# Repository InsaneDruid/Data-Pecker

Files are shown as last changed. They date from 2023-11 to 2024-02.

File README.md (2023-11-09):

# The Data Pecker - a DB High-Res clone
The Data Pecker is a 100% compatible clone of the DB High-Res graphics board for PET/CBM 8000 series computers from 1982.
It implements all the features, with the option to build a 62256-based RAM-board instead of the original one using eight 6116.
Most of the components are readily available. Chips not available from Mouser or Digikey can still be purchased from a variety of sources in China. 

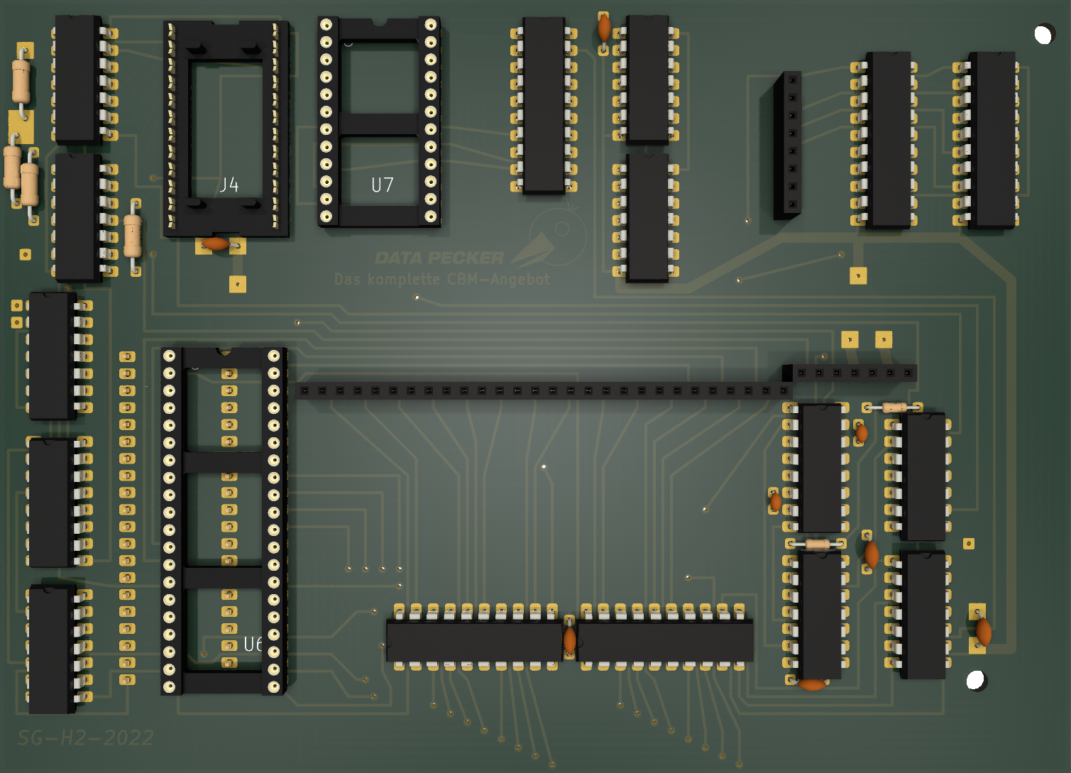
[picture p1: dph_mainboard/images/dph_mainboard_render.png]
Data Pecker render


[Schematic](https://github.com/InsaneDruid/Data-Pecker/blob/main/dph_mainboard/dph_mainboard.pdf "Schematic")  

[Bill of Materials](https://htmlpreview.github.io/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 "Bill of Materials")

[Wire connections](https://github.com/InsaneDruid/Data-Pecker/blob/main/dph_mainboard/dph_mainboard_connections.pdf "Wire connections" )
## The original RAM Board
The is the true-to-the-original version of the RAM board containing eight 6116 SRAM ICs.

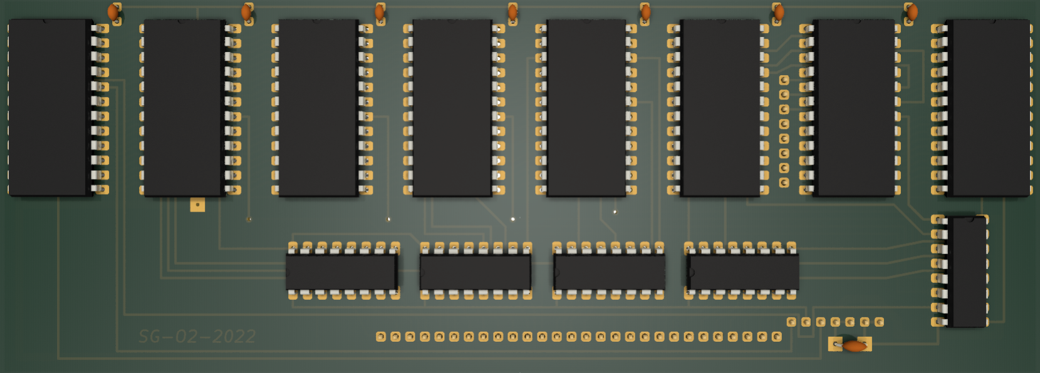
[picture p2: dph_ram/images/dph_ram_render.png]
Original RAM Board render


[Schematic](https://github.com/InsaneDruid/Data-Pecker/blob/main/dph_ram/dph_ram.pdf "Schematic")  

[Bill of Materials](https://htmlpreview.github.io/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 "Bill of Materials")

## The simplified RAM Board
This version replaces the old SRAM chips with a more modern 62256.

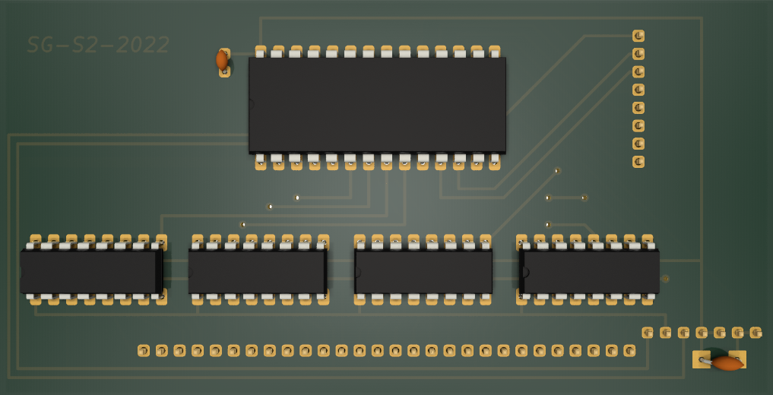
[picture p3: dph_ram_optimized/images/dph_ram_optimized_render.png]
Simplified RAM Board render


[Schematic](https://github.com/InsaneDruid/Data-Pecker/blob/main/dph_ram_optimized/dph_ram_optimized.pdf "Schematic")  

[Bill of Materials](https://htmlpreview.github.io/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 "Bill of Materials")

## The Firmware
There are several ways to get both the programmed 2332A	ROM and TBP18s030 PROM	
chips for the Low Speed Graphik. One is to use U29 and U11 from a original HSG. 
This works well and is especially interesting for those seeking to replace a broken original HSG pcb.

The other possibility is to program a 2532 EPROM replacing U29 and a 18S030 PROM (or compatible, like 82S123, 27S19, 6331, 74S288, 7603a)
replacing U11. The firmware needed for flashing can be found on the web. The 18S030 can also be replaced by a GAL.

## The License
This work is licensed under a Creative Commons Attribution-ShareAlike 4.0 International License.  
See https://creativecommons.org/licenses/by-sa/4.0/.

## The Credits
This work would not have been possible without the help from a bunch of amazing people from [VzEkC e. V. forums](https://forum.classic-computing.de/forum/ "forum.classic-computing.de"). Many thanks go out to:

* *Toast_r* - for providing reference images and ohming out the hidden traces

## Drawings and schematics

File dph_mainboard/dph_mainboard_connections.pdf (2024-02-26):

## IDC PCB connector DIL male, 24-pin, RM 2.54/15.24 ribbon cable

# DATA PECKER wire connections

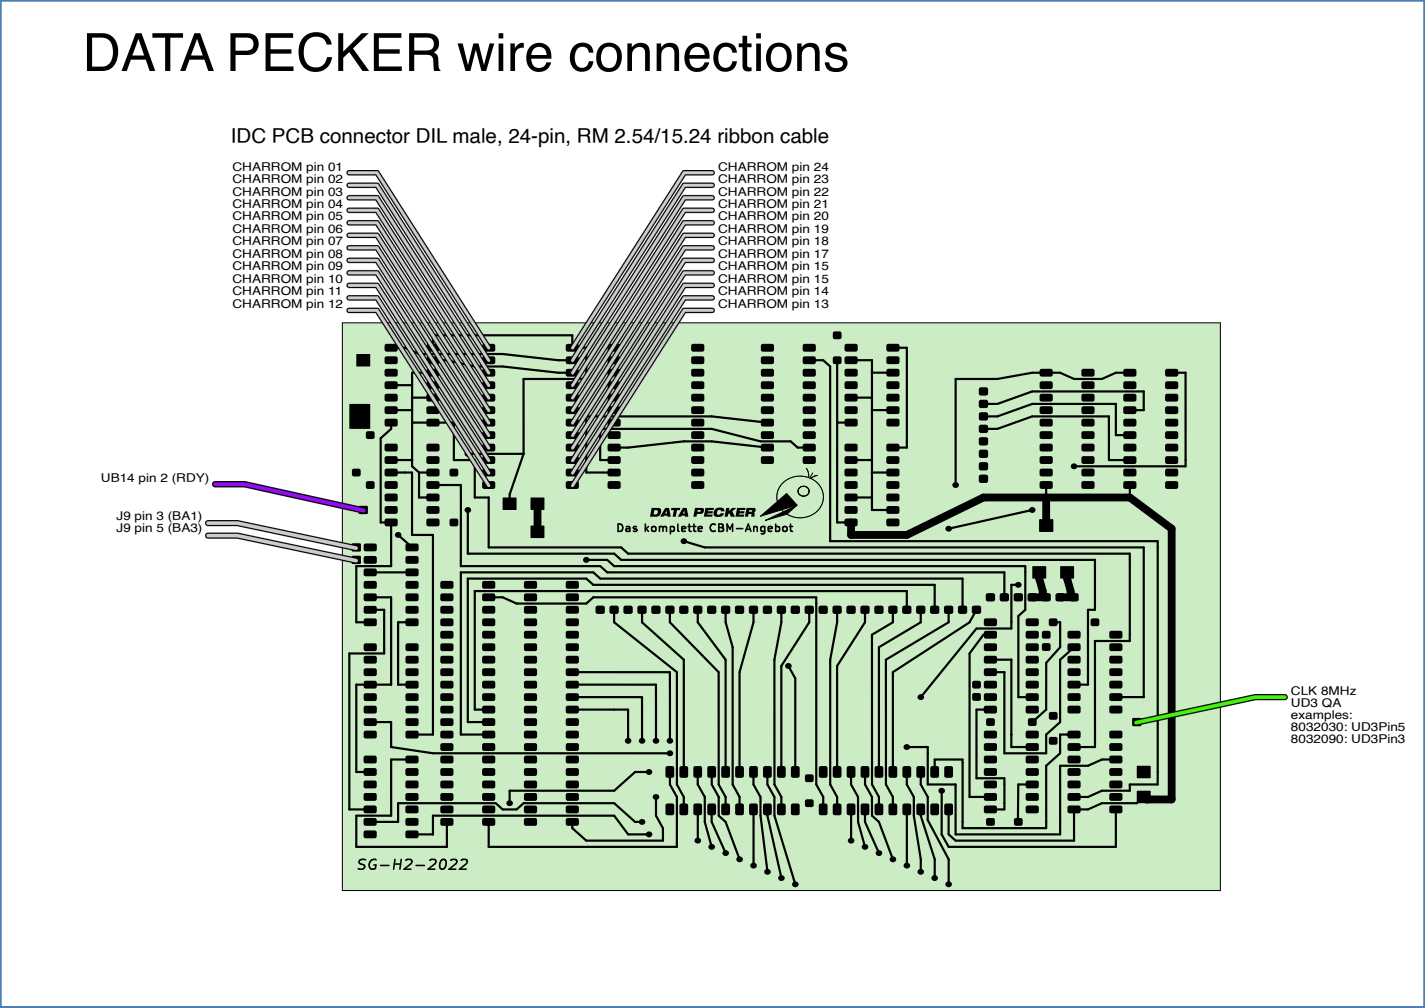
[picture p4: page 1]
CHARROM pin 12; CHARROM pin 24 CHARROM pin 23 CHARROM pin 22 CHARROM pin 21 CHARROM pin 20 CHARROM pin 19 CHARROM pin 18 CHARROM pin 17 CHARROM pin 15 CHARROM pin 15 CHARROM pin 14 CHARROM pin 13; UB14 pin 2 (RDY); J9 pin 3 (BA1); CHARROM pin 01 CHARROM pin 02 CHARROM pin 03 CHARROM pin 04 CHARROM pin 05 CHARROM pin 06 CHARROM pin 07 CHARROM pin 08 CHARROM pin 09 CHARROM pin 10 CHARROM pin 11; J9 pin 5 (BA3); CLK 8MHz UD3 QA examples: 8032030: UD3Pin5 8032090: UD3Pin3

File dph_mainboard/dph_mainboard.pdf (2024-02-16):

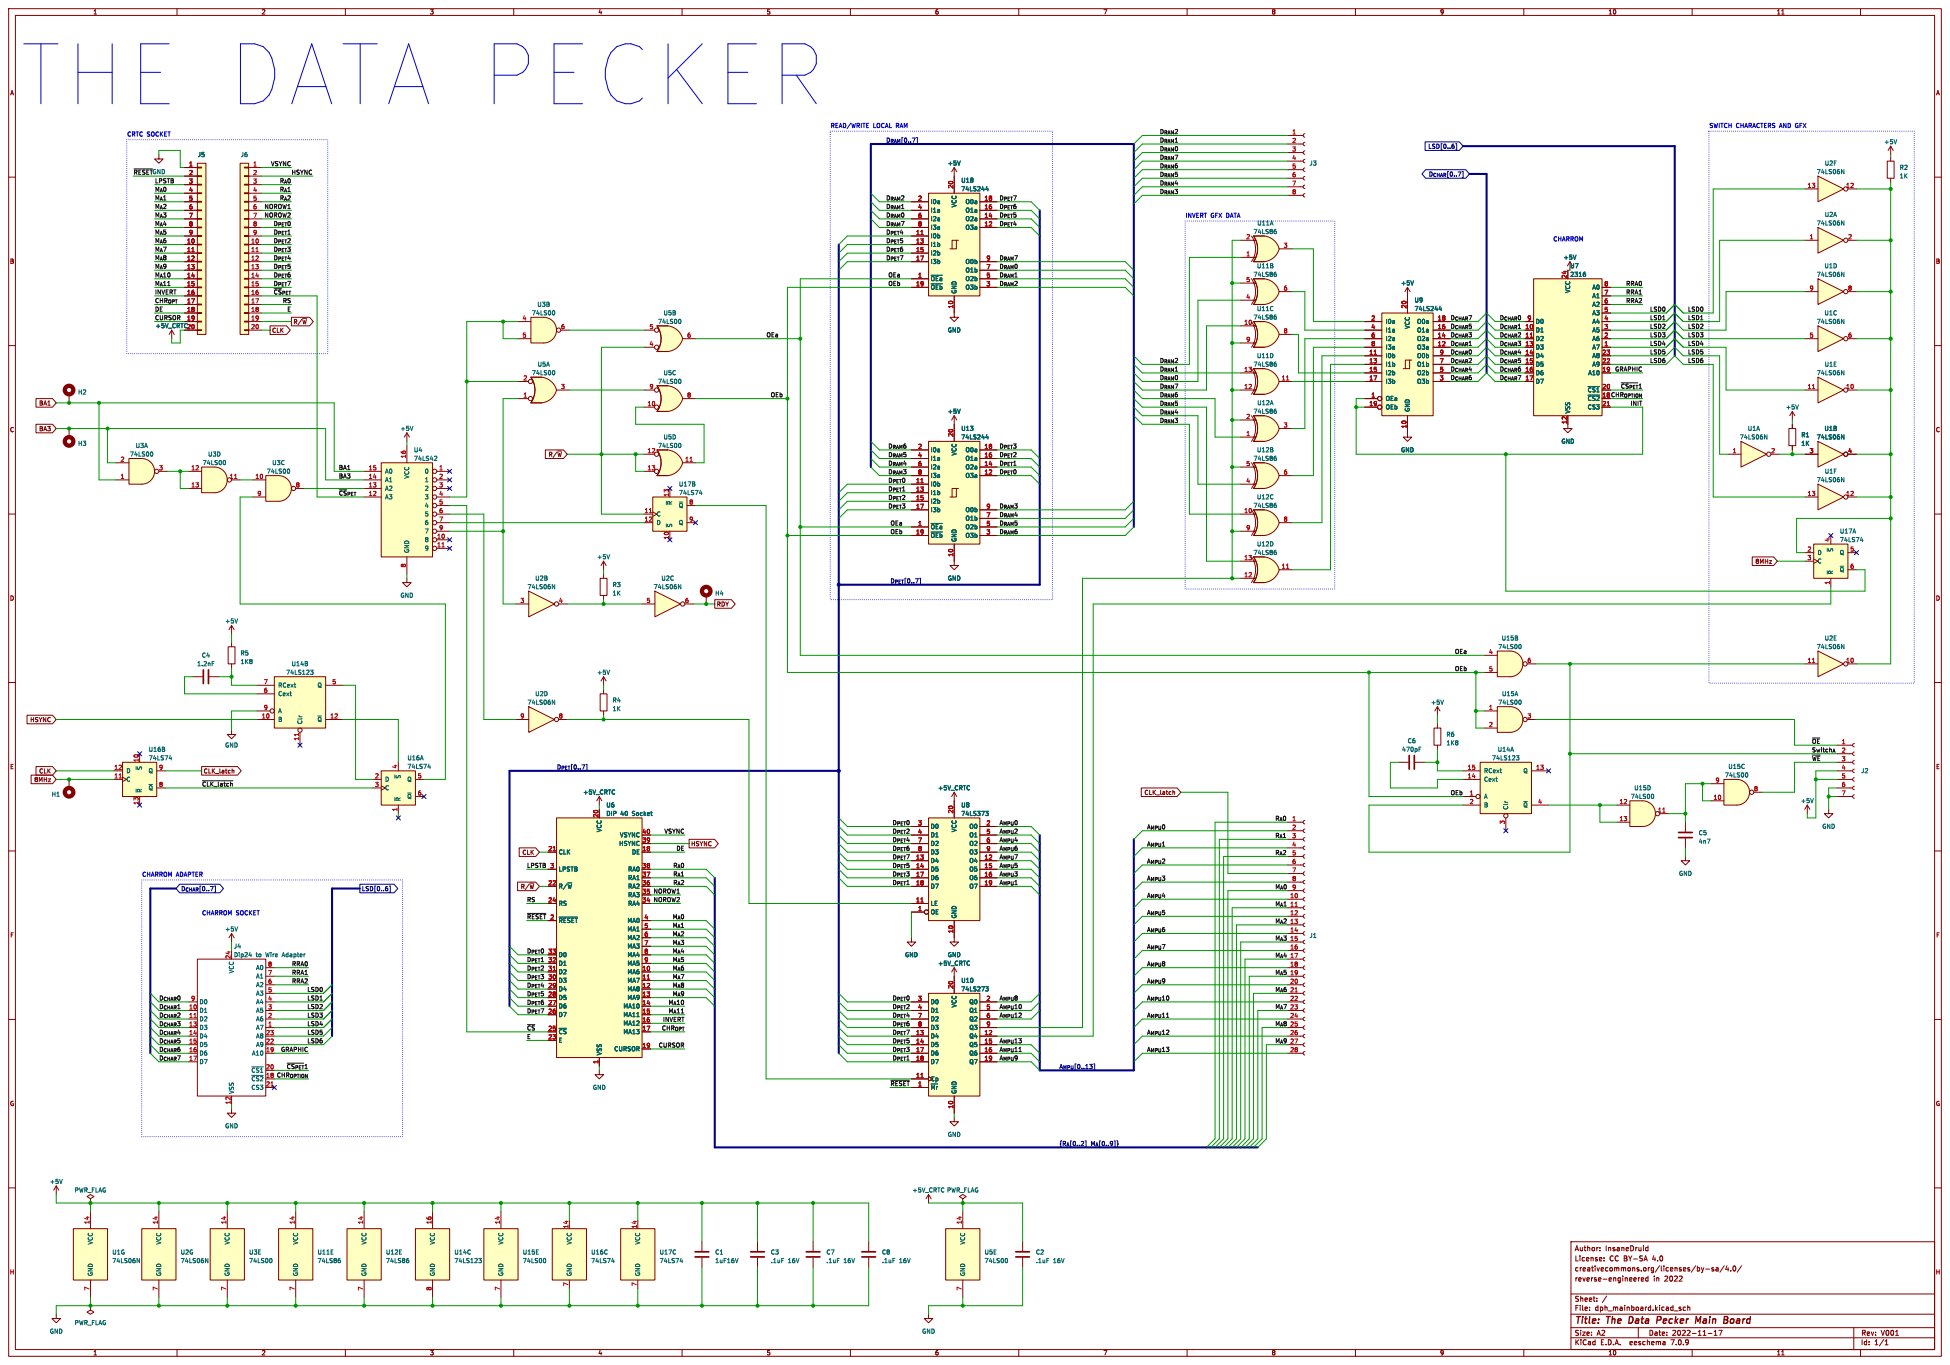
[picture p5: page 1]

SWITCH CHARACTERS AND GFX

1 MA6 10 MA7 11 MA8 12 MA9 13 MA10 14 MA11 15 MA12 16 MA13 17 DE 18 CURSOR 19 ~{RESET} 2 VCC 20 CLK 21 R/~{W} 22 E

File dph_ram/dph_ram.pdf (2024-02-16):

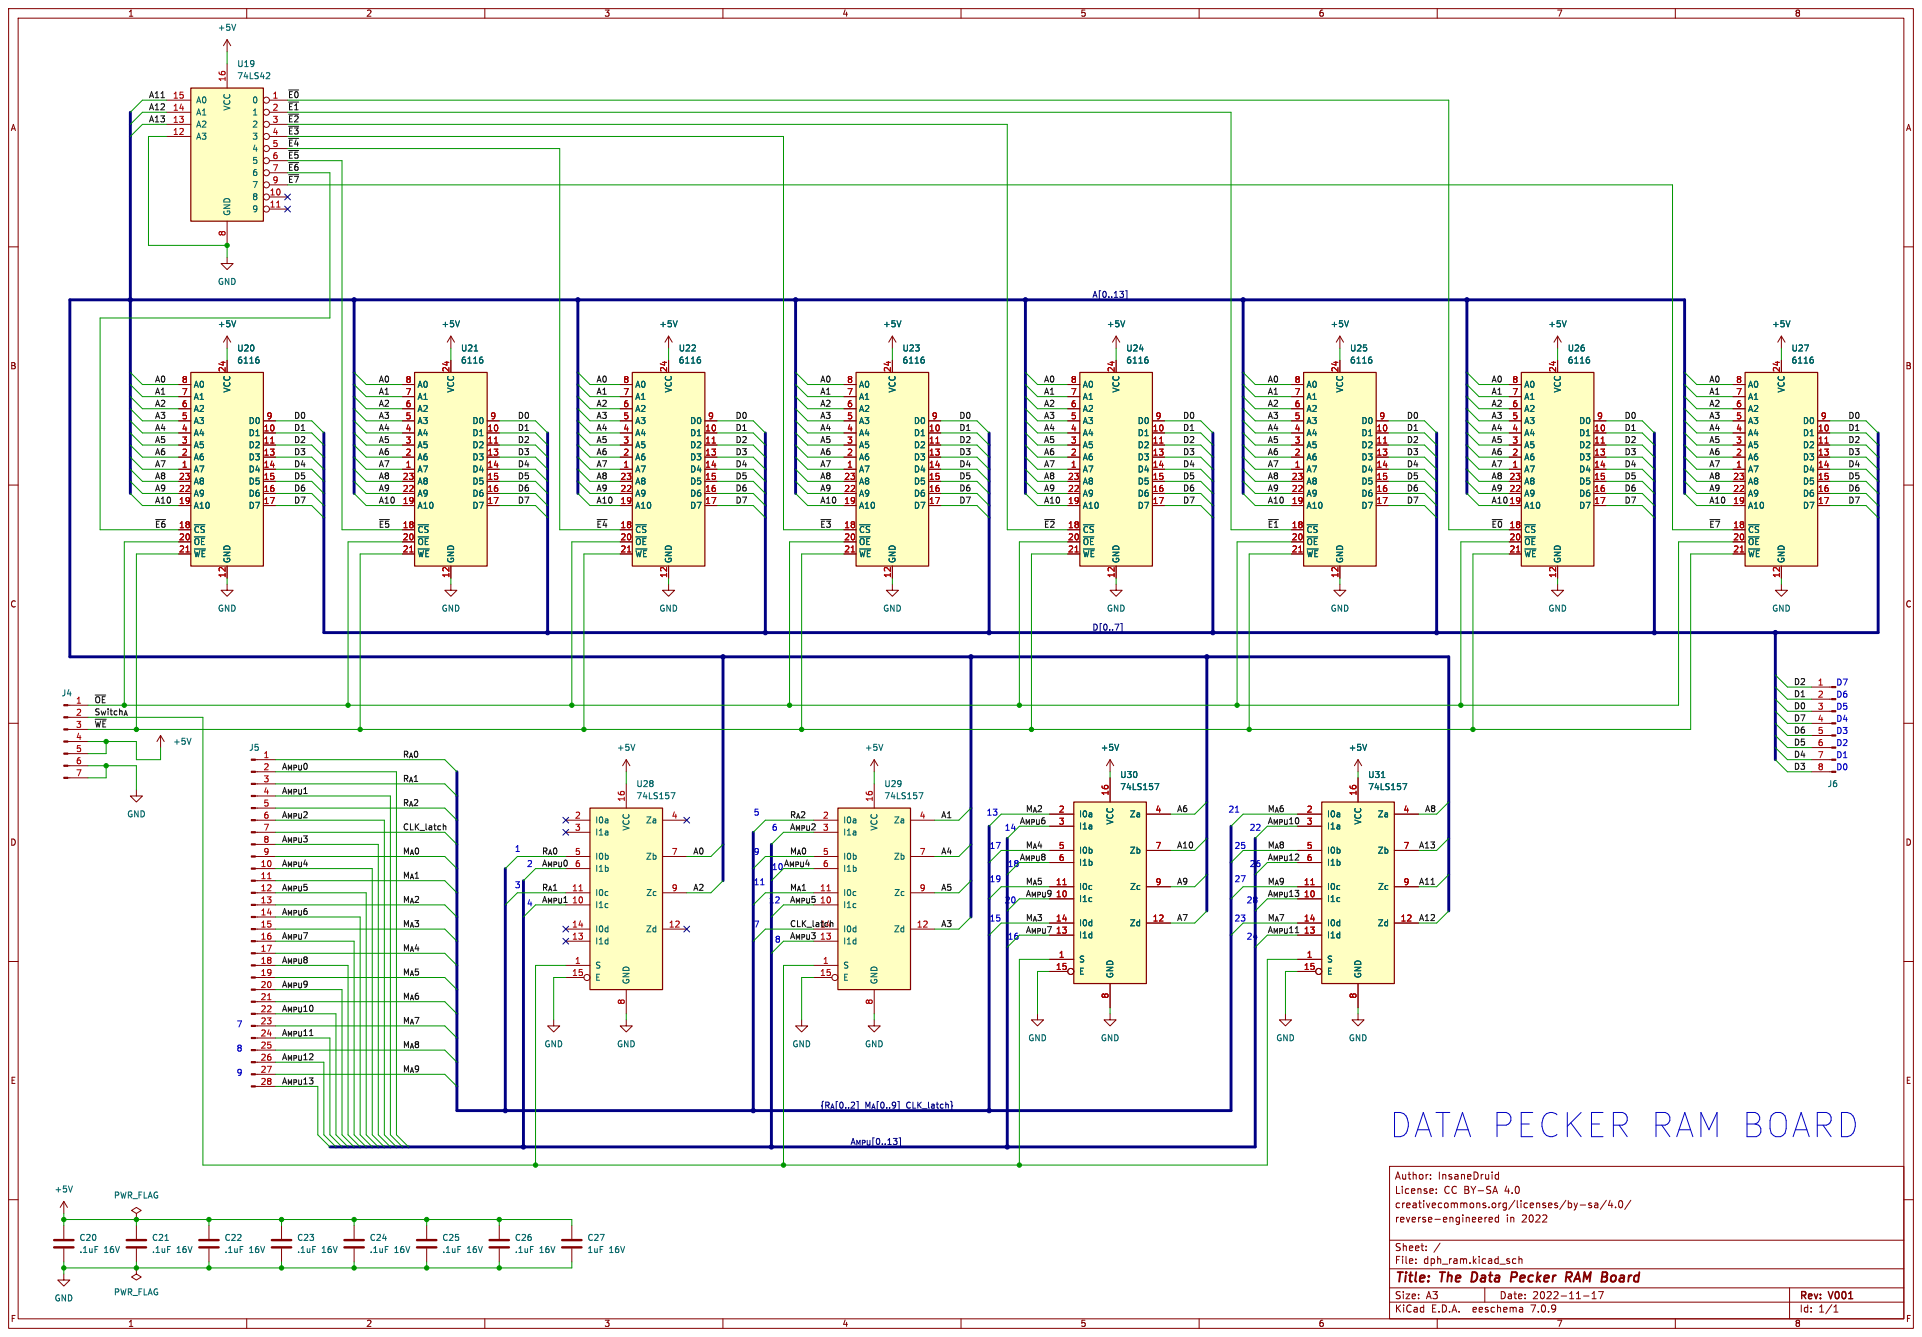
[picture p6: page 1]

Id: 1/1 Title: The Data Pecker RAM Board

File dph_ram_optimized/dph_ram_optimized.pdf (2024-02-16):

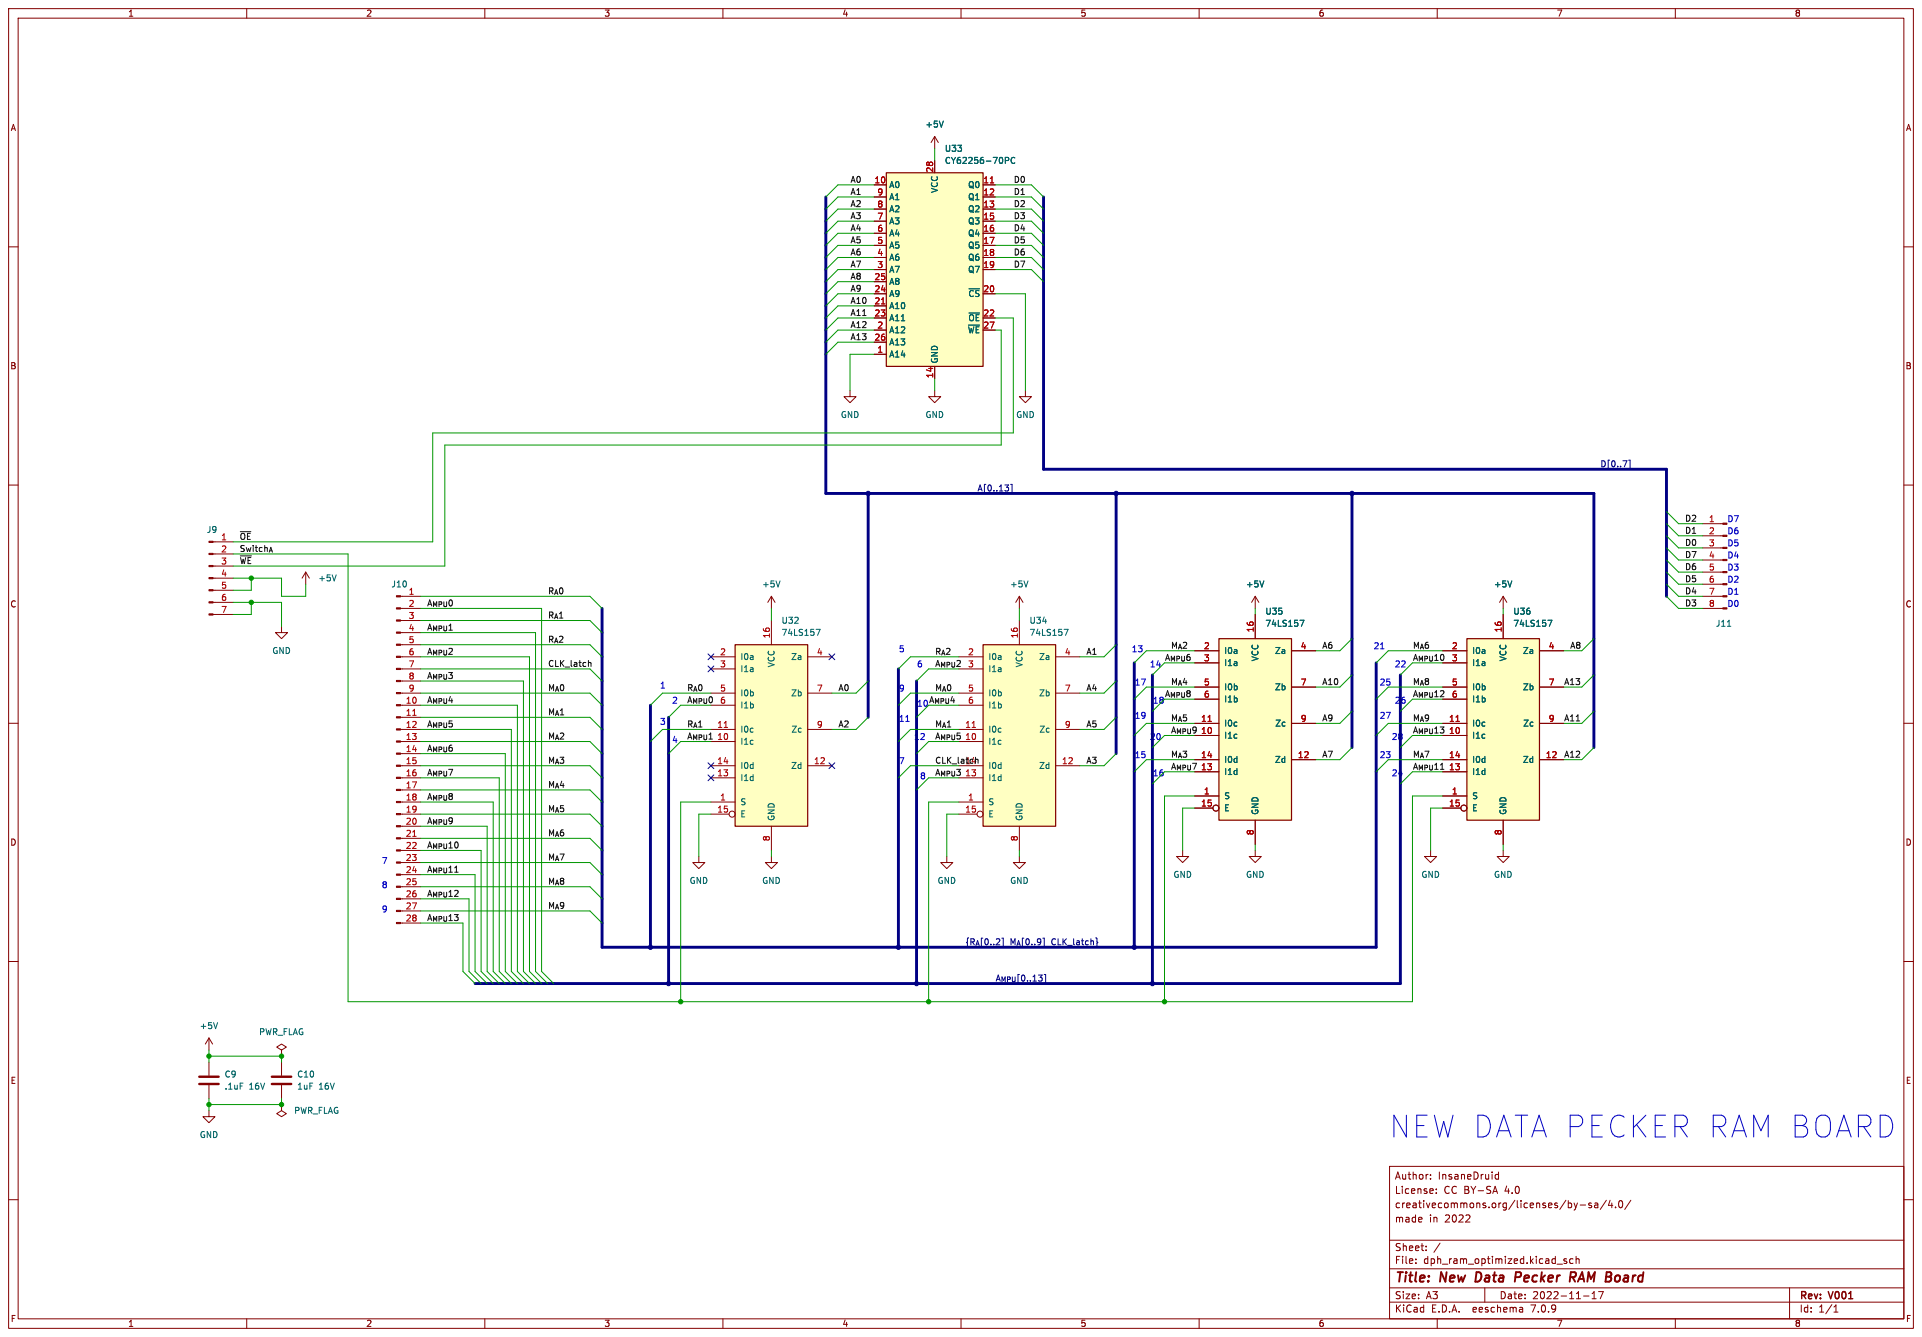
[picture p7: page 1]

File: dph_ram_optimized.kicad_sch Sheet: / made in 2022

Id: 1/1 Title: New Data Pecker RAM Board

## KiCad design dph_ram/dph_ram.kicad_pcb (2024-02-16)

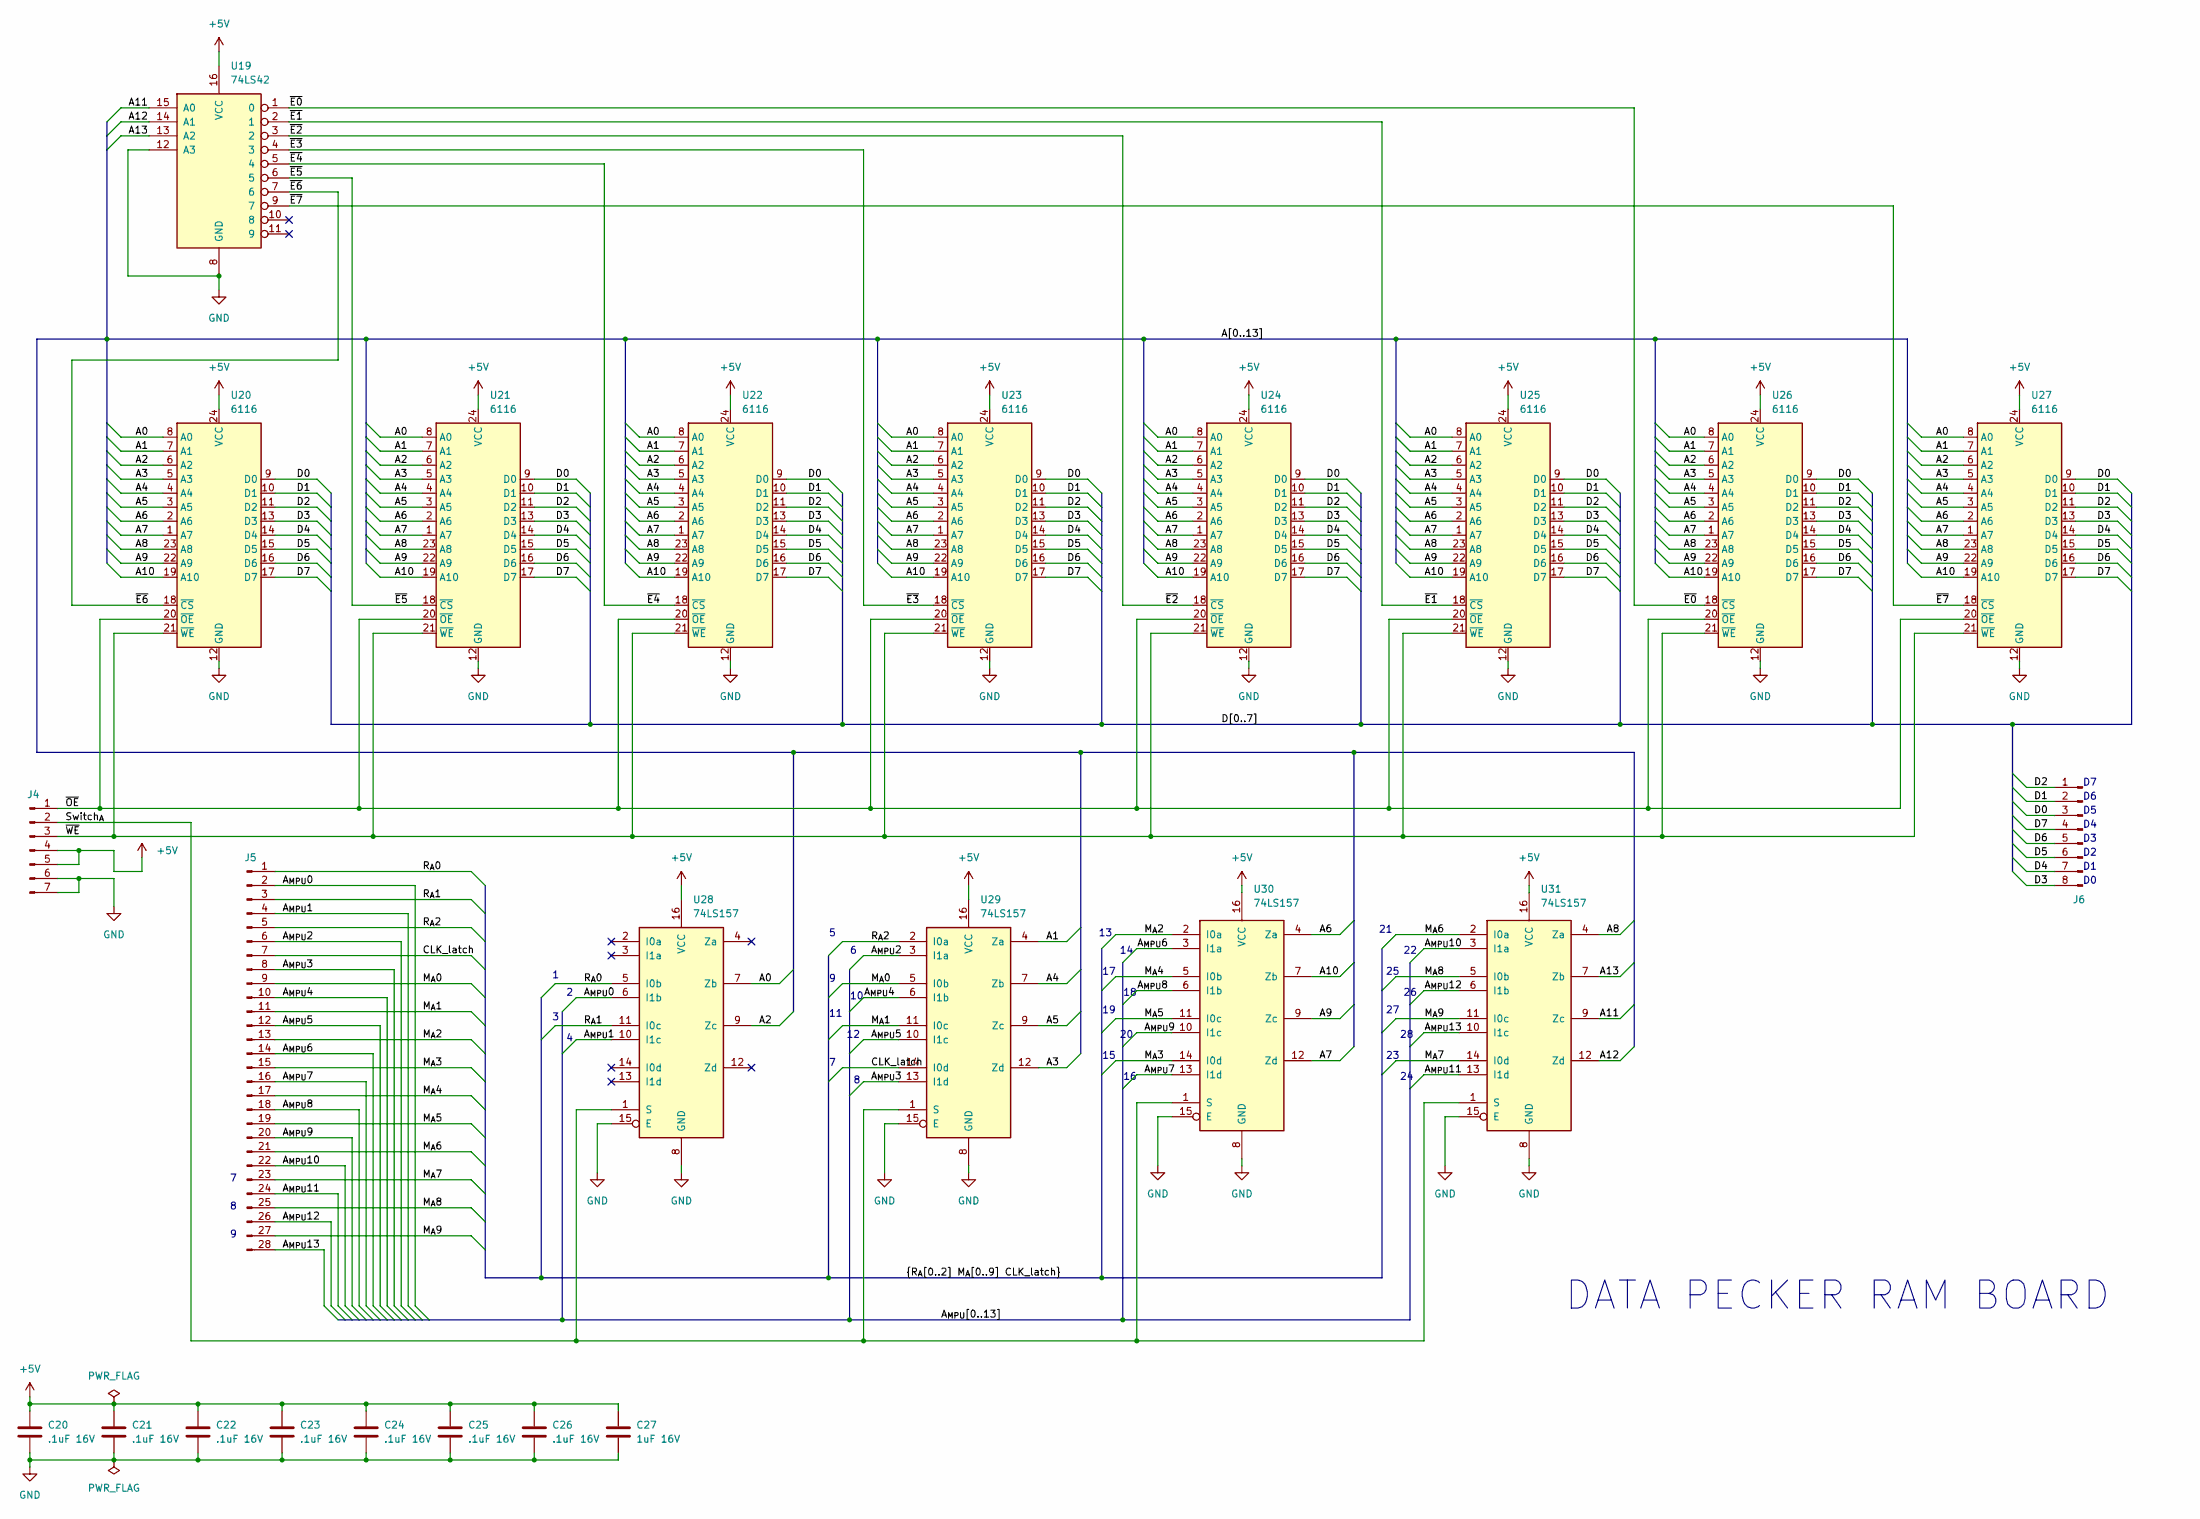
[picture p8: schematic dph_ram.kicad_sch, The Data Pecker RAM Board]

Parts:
C20, C21, C22, C23, C24, C25, C26: .1uF 16V; C_Disc_D3.0mm_W1.6mm_P2.50mm
C27: 1uF 16V; C_Disc_D4.3mm_W1.9mm_P5.08mm
J4: Conn_01x07_Pin; PinHeader_1x07_P2.54mm_Vertical
J5: Conn_01x28_Pin; PinHeader_1x28_P2.54mm_Vertical
J6: Conn_01x08_Pin; PinHeader_1x08_P2.54mm_Vertical
U19: 74LS42; DIP-16_W7.62mm_LongPads
U20, U21, U22, U23, U24, U25, U26, U27: 6116; DIP-24_W15.24mm_LongPads
U28, U29, U30, U31: 74LS157; DIP-16_W7.62mm_LongPads

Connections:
+5V: C20.1, C21.1, C22.1, C23.1, C24.1, C25.1, C26.1, C27.1, J4.4, J4.5, U19.16 (VCC), U20.24 (VCC), U21.24 (VCC), U22.24 (VCC), U23.24 (VCC), U24.24 (VCC), U25.24 (VCC), U26.24 (VCC), U27.24 (VCC), U28.16 (VCC), U29.16 (VCC), U30.16 (VCC), U31.16 (VCC)
/A0: U20.8 (A0), U21.8 (A0), U22.8 (A0), U23.8 (A0), U24.8 (A0), U25.8 (A0), U26.8 (A0), U27.8 (A0), U28.7 (Zb)
/A1: U20.7 (A1), U21.7 (A1), U22.7 (A1), U23.7 (A1), U24.7 (A1), U25.7 (A1), U26.7 (A1), U27.7 (A1), U29.4 (Za)
/A2: U20.6 (A2), U21.6 (A2), U22.6 (A2), U23.6 (A2), U24.6 (A2), U25.6 (A2), U26.6 (A2), U27.6 (A2), U28.9 (Zc)
/A3: U20.5 (A3), U21.5 (A3), U22.5 (A3), U23.5 (A3), U24.5 (A3), U25.5 (A3), U26.5 (A3), U27.5 (A3), U29.12 (Zd)
/A4: U20.4 (A4), U21.4 (A4), U22.4 (A4), U23.4 (A4), U24.4 (A4), U25.4 (A4), U26.4 (A4), U27.4 (A4), U29.7 (Zb)
/A5: U20.3 (A5), U21.3 (A5), U22.3 (A5), U23.3 (A5), U24.3 (A5), U25.3 (A5), U26.3 (A5), U27.3 (A5), U29.9 (Zc)
/A6: U20.2 (A6), U21.2 (A6), U22.2 (A6), U23.2 (A6), U24.2 (A6), U25.2 (A6), U26.2 (A6), U27.2 (A6), U30.4 (Za)
/A7: U20.1 (A7), U21.1 (A7), U22.1 (A7), U23.1 (A7), U24.1 (A7), U25.1 (A7), U26.1 (A7), U27.1 (A7), U30.12 (Zd)
/A8: U20.23 (A8), U21.23 (A8), U22.23 (A8), U23.23 (A8), U24.23 (A8), U25.23 (A8), U26.23 (A8), U27.23 (A8), U31.4 (Za)
/A9: U20.22 (A9), U21.22 (A9), U22.22 (A9), U23.22 (A9), U24.22 (A9), U25.22 (A9), U26.22 (A9), U27.22 (A9), U30.9 (Zc)
/A10: U20.19 (A10), U21.19 (A10), U22.19 (A10), U23.19 (A10), U24.19 (A10), U25.19 (A10), U26.19 (A10), U27.19 (A10), U30.7 (Zb)
/A11: U19.15 (A0), U31.9 (Zc)
/A12: U19.14 (A1), U31.12 (Zd)
/A13: U19.13 (A2), U31.7 (Zb)
/A_{MPU}0: J5.2, U28.6 (I1b)
/A_{MPU}1: J5.4, U28.10 (I1c)
/A_{MPU}2: J5.6, U29.3 (I1a)
/A_{MPU}3: J5.8, U29.13 (I1d)
/A_{MPU}4: J5.10, U29.6 (I1b)
/A_{MPU}5: J5.12, U29.10 (I1c)
/A_{MPU}6: J5.14, U30.3 (I1a)
/A_{MPU}7: J5.16, U30.13 (I1d)
/A_{MPU}8: J5.18, U30.6 (I1b)
/A_{MPU}9: J5.20, U30.10 (I1c)
/A_{MPU}10: J5.22, U31.3 (I1a)
/A_{MPU}11: J5.24, U31.13 (I1d)
/A_{MPU}12: J5.26, U31.6 (I1b)
/A_{MPU}13: J5.28, U31.10 (I1c)
/CLK_latch: J5.7, U29.14 (I0d)
/D0: J6.3, U20.9 (D0), U21.9 (D0), U22.9 (D0), U23.9 (D0), U24.9 (D0), U25.9 (D0), U26.9 (D0), U27.9 (D0)
/D1: J6.2, U20.10 (D1), U21.10 (D1), U22.10 (D1), U23.10 (D1), U24.10 (D1), U25.10 (D1), U26.10 (D1), U27.10 (D1)
/D2: J6.1, U20.11 (D2), U21.11 (D2), U22.11 (D2), U23.11 (D2), U24.11 (D2), U25.11 (D2), U26.11 (D2), U27.11 (D2)
/D3: J6.8, U20.13 (D3), U21.13 (D3), U22.13 (D3), U23.13 (D3), U24.13 (D3), U25.13 (D3), U26.13 (D3), U27.13 (D3)
/D4: J6.7, U20.14 (D4), U21.14 (D4), U22.14 (D4), U23.14 (D4), U24.14 (D4), U25.14 (D4), U26.14 (D4), U27.14 (D4)
/D5: J6.6, U20.15 (D5), U21.15 (D5), U22.15 (D5), U23.15 (D5), U24.15 (D5), U25.15 (D5), U26.15 (D5), U27.15 (D5)
/D6: J6.5, U20.16 (D6), U21.16 (D6), U22.16 (D6), U23.16 (D6), U24.16 (D6), U25.16 (D6), U26.16 (D6), U27.16 (D6)
/D7: J6.4, U20.17 (D7), U21.17 (D7), U22.17 (D7), U23.17 (D7), U24.17 (D7), U25.17 (D7), U26.17 (D7), U27.17 (D7)
/M_{A}0: J5.9, U29.5 (I0b)
/M_{A}1: J5.11, U29.11 (I0c)
/M_{A}2: J5.13, U30.2 (I0a)
/M_{A}3: J5.15, U30.14 (I0d)
/M_{A}4: J5.17, U30.5 (I0b)
/M_{A}5: J5.19, U30.11 (I0c)
/M_{A}6: J5.21, U31.2 (I0a)
/M_{A}7: J5.23, U31.14 (I0d)
/M_{A}8: J5.25, U31.5 (I0b)
/M_{A}9: J5.27, U31.11 (I0c)
/R_{A}0: J5.1, U28.5 (I0b)
/R_{A}1: J5.3, U28.11 (I0c)
/R_{A}2: J5.5, U29.2 (I0a)
/Switch_{A}: J4.2, U28.1 (S), U29.1 (S), U30.1 (S), U31.1 (S)
/~E0: U19.1 (0), U26.18 (~CS)
/~E1: U19.2 (1), U25.18 (~CS)
/~E2: U19.3 (2), U24.18 (~CS)
/~E3: U19.4 (3), U23.18 (~CS)
/~E4: U19.5 (4), U22.18 (~CS)
/~E5: U19.6 (5), U21.18 (~CS)
/~E6: U19.7 (6), U20.18 (~CS)
/~E7: U19.9 (7), U27.18 (~CS)
/~OE: J4.1, U20.20 (~OE), U21.20 (~OE), U22.20 (~OE), U23.20 (~OE), U24.20 (~OE), U25.20 (~OE), U26.20 (~OE), U27.20 (~OE)
/~WE: J4.3, U20.21 (~WE), U21.21 (~WE), U22.21 (~WE), U23.21 (~WE), U24.21 (~WE), U25.21 (~WE), U26.21 (~WE), U27.21 (~WE)
GND: C20.2, C21.2, C22.2, C23.2, C24.2, C25.2, C26.2, C27.2, J4.6, J4.7, U19.8 (GND), U19.12 (A3), U20.12 (GND), U21.12 (GND), U22.12 (GND), U23.12 (GND), U24.12 (GND), U25.12 (GND), U26.12 (GND), U27.12 (GND), U28.8 (GND), U28.15 (E), U29.8 (GND), U29.15 (E), U30.8 (GND), U30.15 (E), U31.8 (GND), U31.15 (E)

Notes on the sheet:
DATA PECKER RAM BOARD

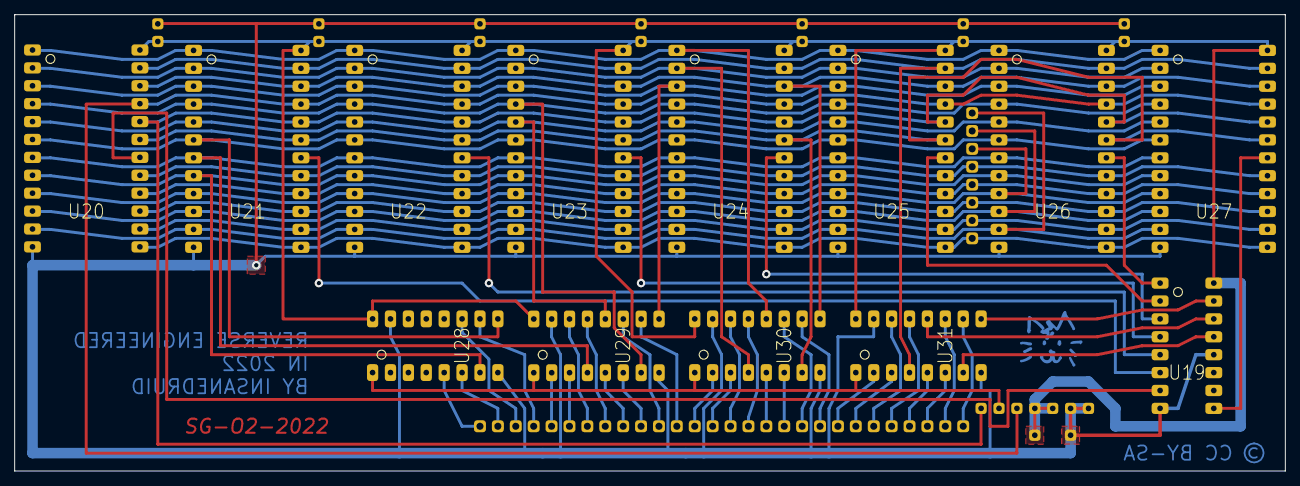
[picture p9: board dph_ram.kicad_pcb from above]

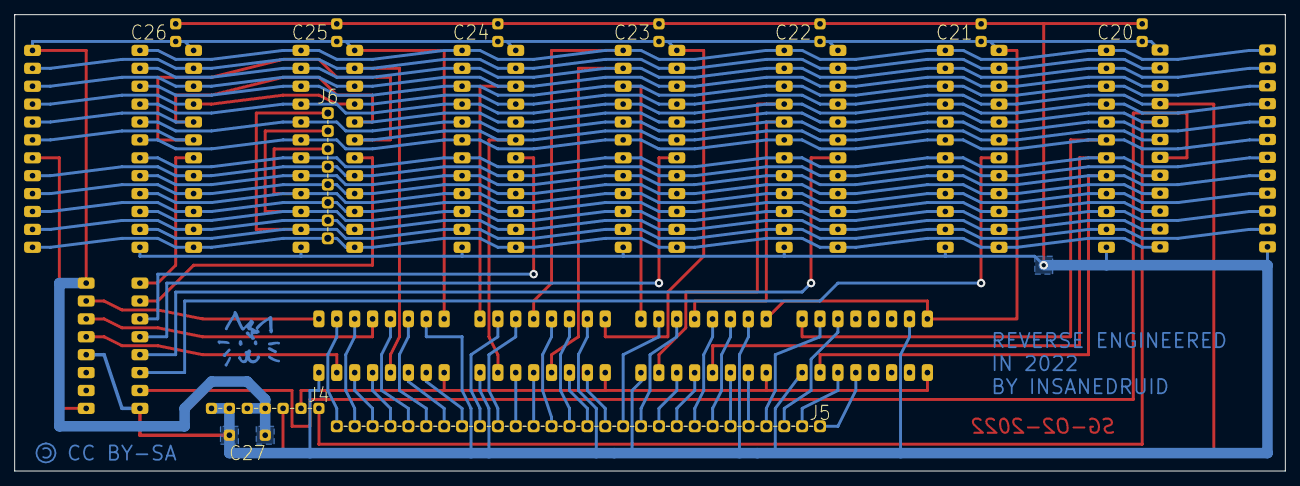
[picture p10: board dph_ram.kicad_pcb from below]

Board: 2 copper layers, 180.3 x 64.8 mm, 24 parts (3 on the bottom side), 63 nets.

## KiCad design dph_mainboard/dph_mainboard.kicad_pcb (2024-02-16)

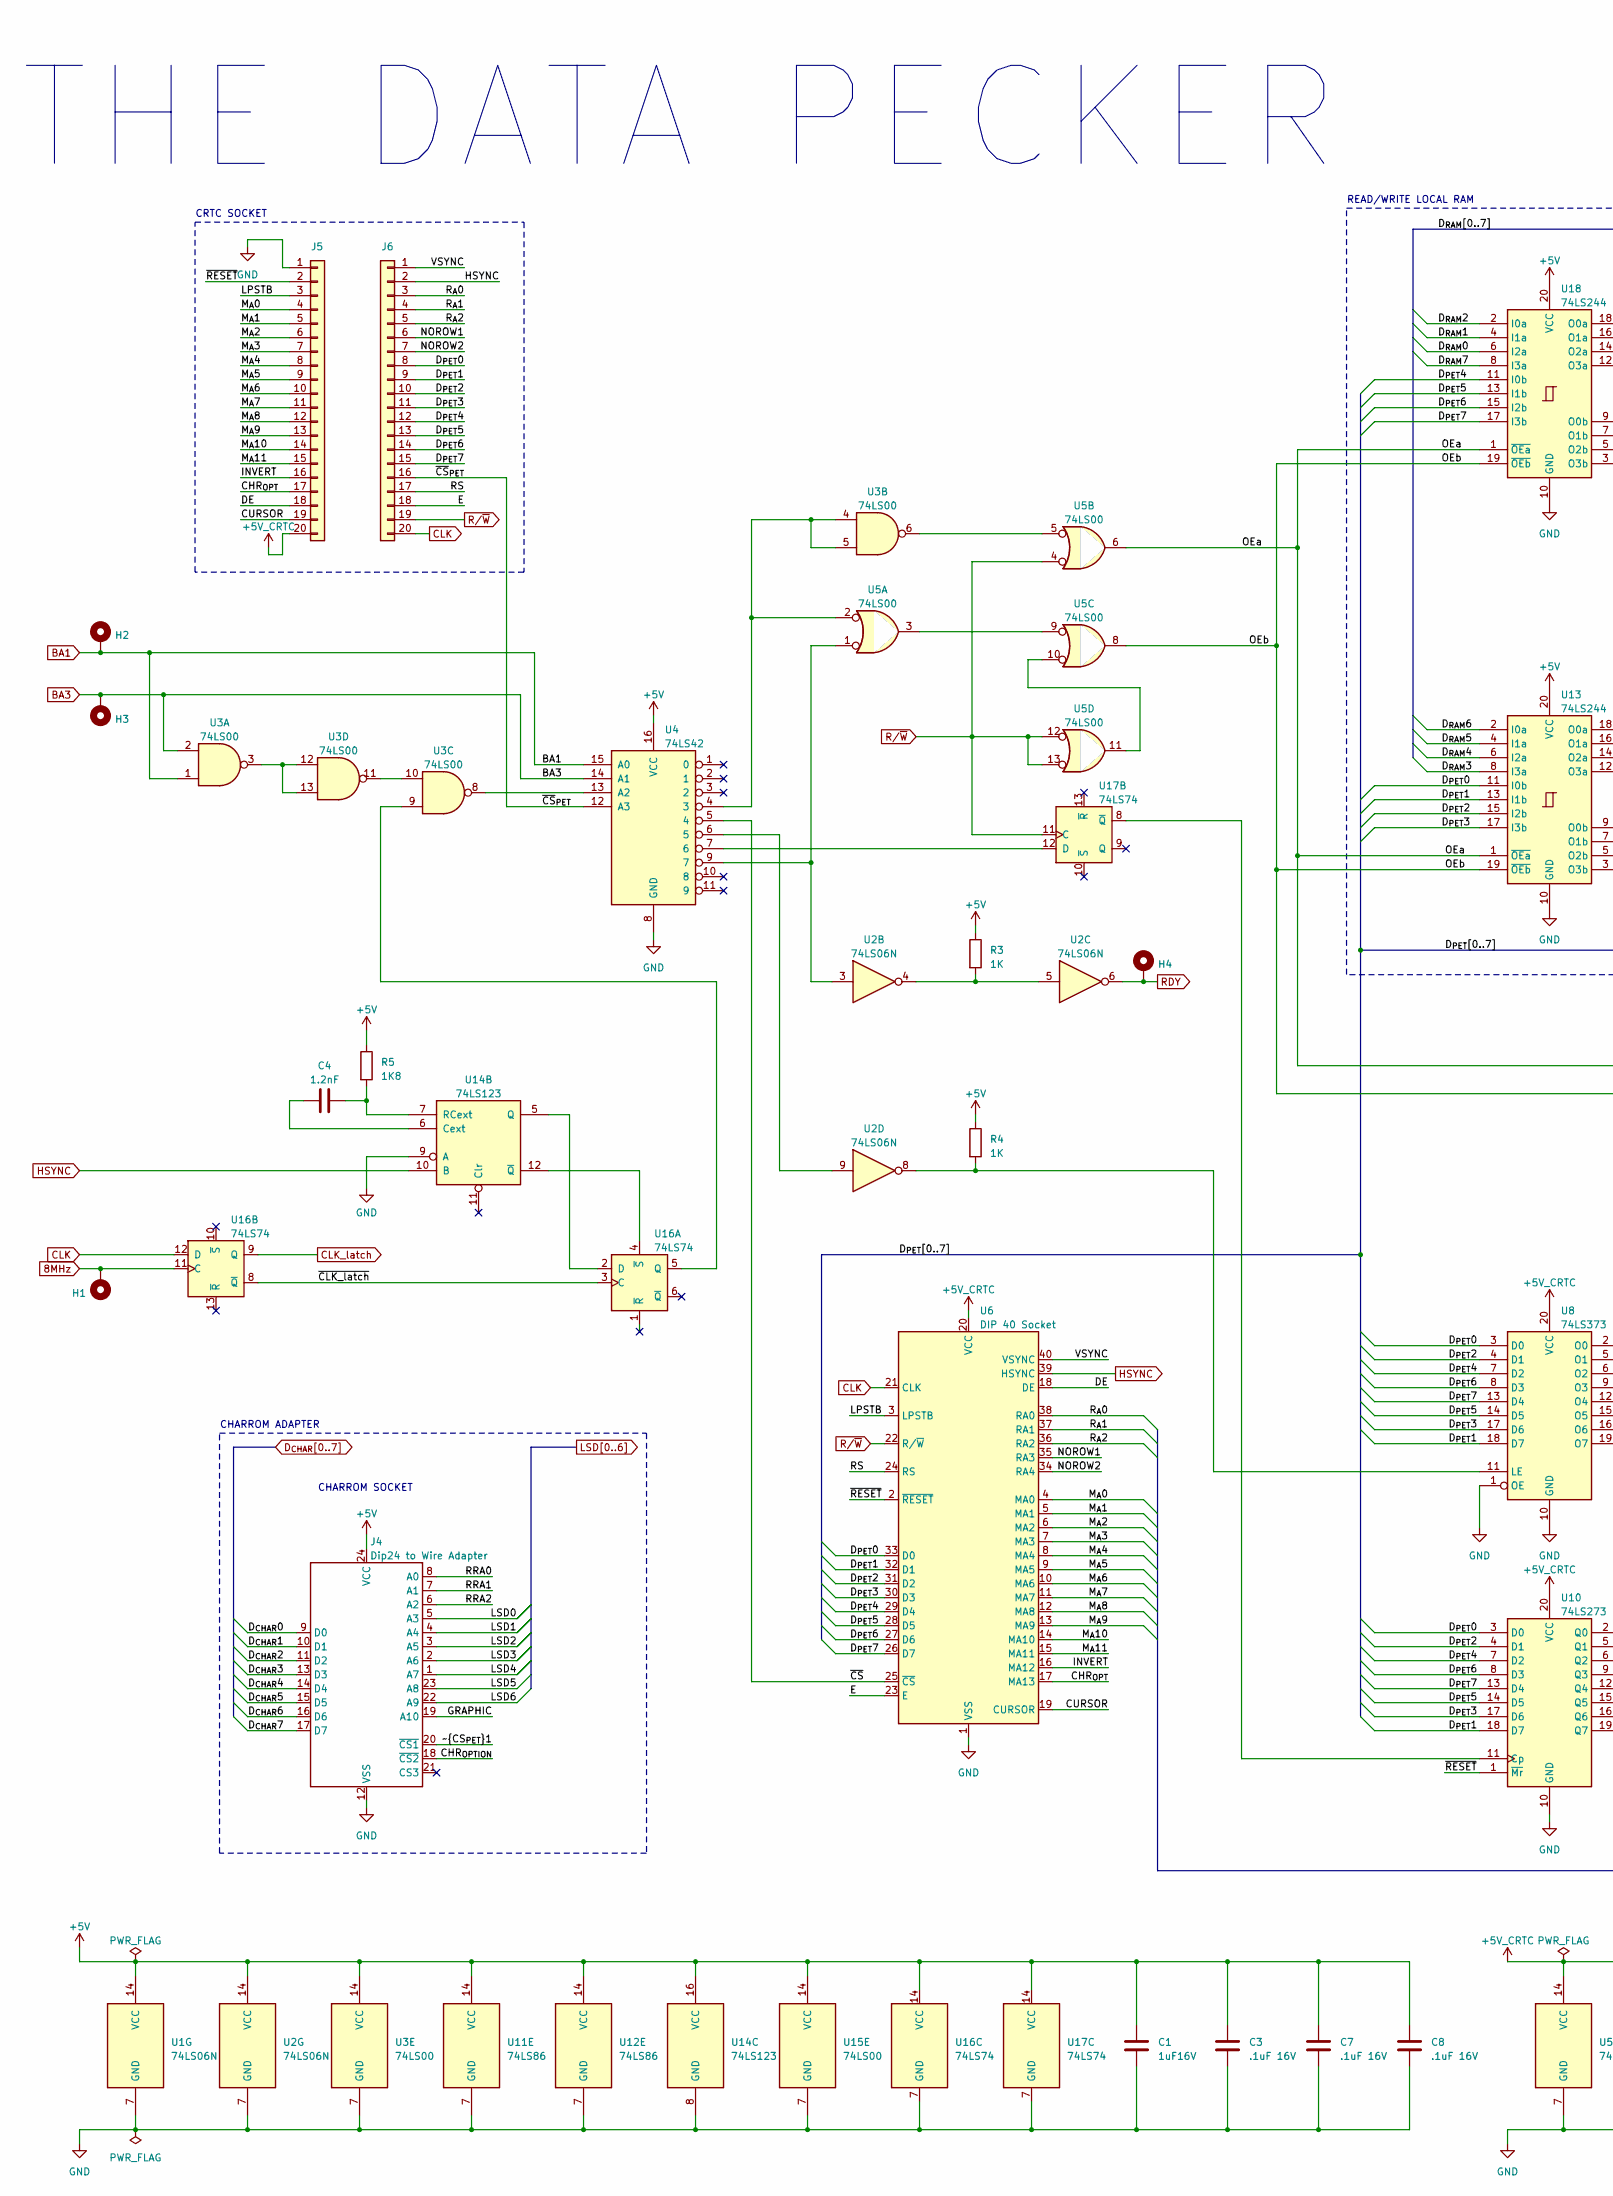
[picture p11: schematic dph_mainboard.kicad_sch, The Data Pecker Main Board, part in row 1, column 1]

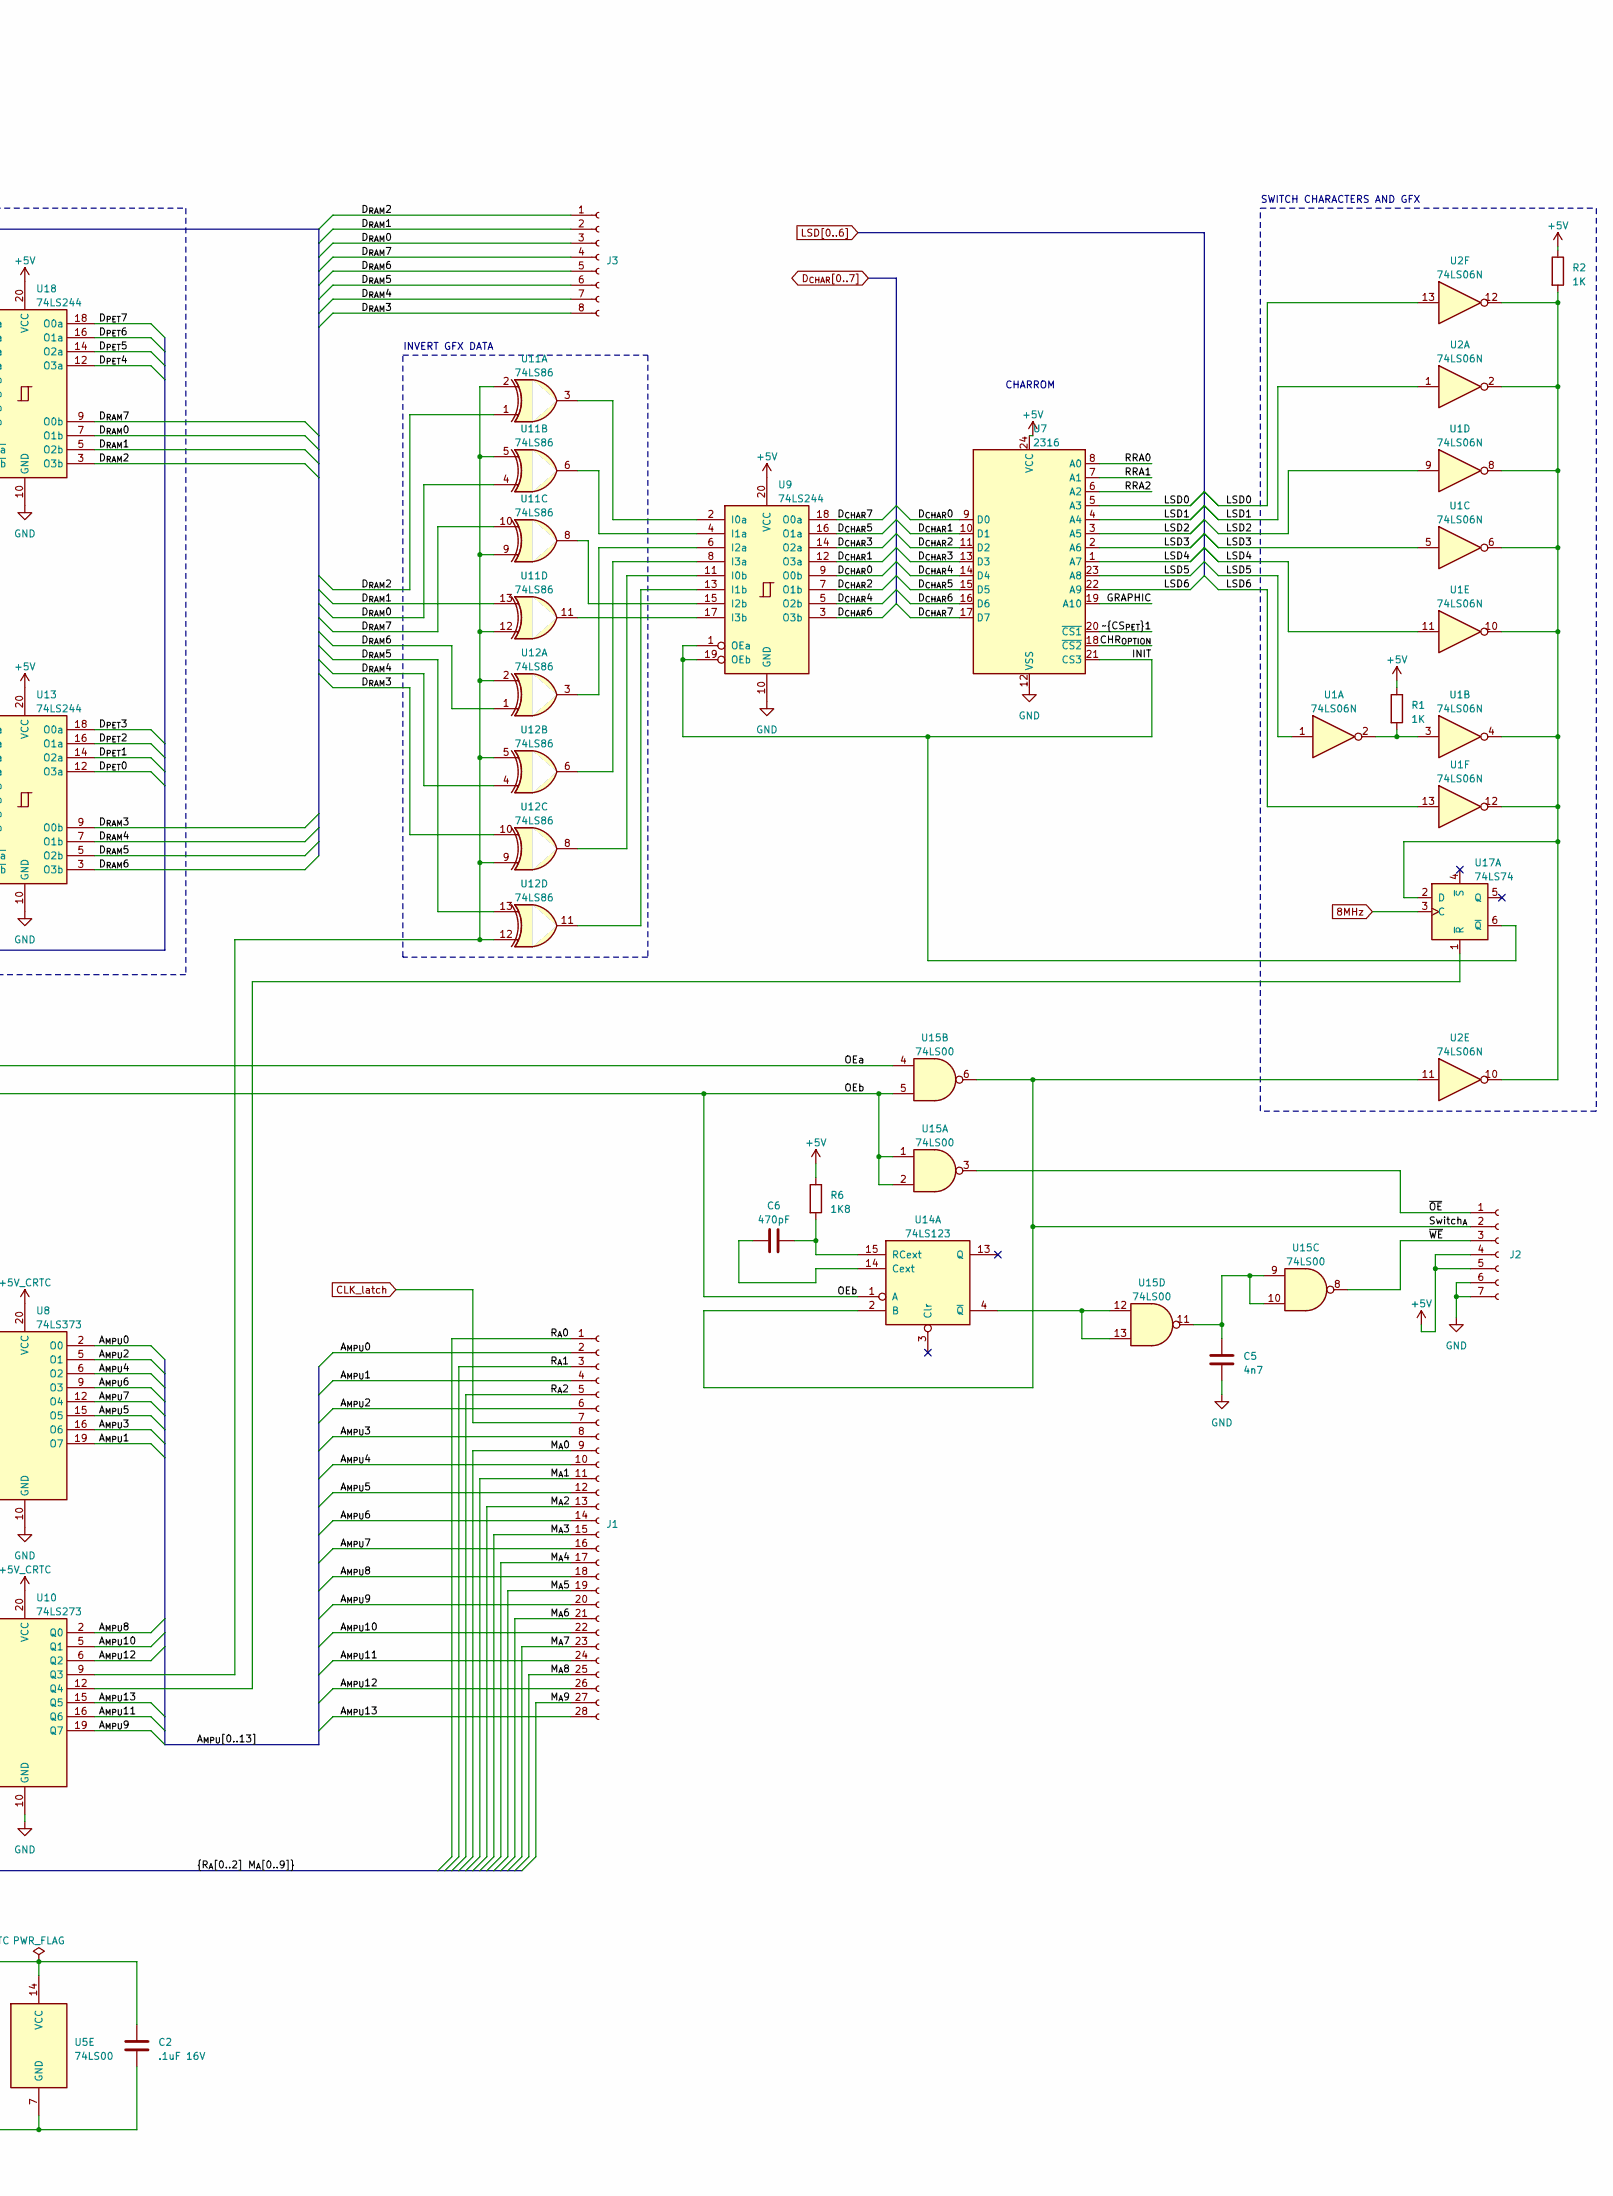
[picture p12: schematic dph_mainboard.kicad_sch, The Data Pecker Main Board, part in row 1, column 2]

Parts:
C1: 1uF16V; C_Disc_D4.3mm_W1.9mm_P5.08mm
C2, C3, C7, C8: .1uF 16V; C_Disc_D4.3mm_W1.9mm_P5.08mm
C4: 1.2nF; C_Disc_D3.0mm_W1.6mm_P2.50mm
C5: 4n7; C_Disc_D4.3mm_W1.9mm_P5.08mm
C6: 470pF; C_Disc_D3.0mm_W1.6mm_P2.50mm
H1, H2, H3, H4: MountingHole_Pad; SolderWire-0.15sqmm_1x01_D0.5mm_OD1.5mm
J1: Conn_01x28_Socket; PinSocket_1x28_P2.54mm_Vertical
J2: Conn_01x7_Socket; PinSocket_1x07_P2.54mm_Vertical
J3: Conn_01x8_Socket; PinSocket_1x08_P2.54mm_Vertical
J4: Dip24 to Wire Adapter; DIP-24_W15.24mm_WireAdapter
J5, J6: Conn_01x20_Pin; PinHeader_1x20_P2.54mm_Vertical
R1, R2, R3, R4: 1K; R_Axial_DIN0207_L6.3mm_D2.5mm_P10.16mm_Horizontal
R5, R6: 1K8; R_Axial_DIN0204_L3.6mm_D1.6mm_P7.62mm_Horizontal
U1, U2: 74LS06N; DIP-14_W7.62mm_LongPads
U3, U5, U15: 74LS00; DIP-14_W7.62mm_LongPads
U4: 74LS42; DIP-16_W7.62mm_LongPads
U6: DIP 40 Socket; DIP-40_W15.24mm_Socket_LongPads
U7: 2316; DIP-24_W15.24mm_Socket_LongPads
U8: 74LS373; DIP-20_W7.62mm_LongPads
U9, U13, U18: 74LS244; DIP-20_W7.62mm_LongPads
U10: 74LS273; DIP-20_W7.62mm_LongPads
U11, U12: 74LS86; DIP-14_W7.62mm_LongPads
U14: 74LS123; DIP-16_W7.62mm_LongPads
U16, U17: 74LS74; DIP-14_W7.62mm_LongPads

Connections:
8MHz: H1.1, U16.11 (C), U17.3 (C)
+5V: C1.1, C3.1, C7.1, C8.1, J2.4, J2.5, J4.24 (VCC), R1.1, R2.1, R3.1, R4.1, R5.1, R6.1, U1.14 (VCC), U2.14 (VCC), U3.14 (VCC), U4.16 (VCC), U7.24 (VCC), U9.20 (VCC), U11.14 (VCC), U12.14 (VCC), U13.20 (VCC), U14.16 (VCC), U15.14 (VCC), U16.14 (VCC), U17.14 (VCC), U18.20 (VCC)
+5V_CRTC: C2.1, J5.20, U5.14 (VCC), U6.20 (VCC), U8.20 (VCC), U10.20 (VCC)
/A_{MPU}0: J1.2, U8.2 (O0)
/A_{MPU}1: J1.4, U8.19 (O7)
/A_{MPU}2: J1.6, U8.5 (O1)
/A_{MPU}3: J1.8, U8.16 (O6)
/A_{MPU}4: J1.10, U8.6 (O2)
/A_{MPU}5: J1.12, U8.15 (O5)
/A_{MPU}6: J1.14, U8.9 (O3)
/A_{MPU}7: J1.16, U8.12 (O4)
/A_{MPU}8: J1.18, U10.2 (Q0)
/A_{MPU}9: J1.20, U10.19 (Q7)
/A_{MPU}10: J1.22, U10.5 (Q1)
/A_{MPU}11: J1.24, U10.16 (Q6)
/A_{MPU}12: J1.26, U10.6 (Q2)
/A_{MPU}13: J1.28, U10.15 (Q5)
/CHR_{OPTION}: J4.18 (~CS2), U7.18 (~CS2)
/CHR_{OPT}: J5.17, U6.17 (MA13)
/CURSOR: J5.19, U6.19 (CURSOR)
/DE: J5.18, U6.18 (DE)
/D_{PET}0: J6.8, U6.33 (D0), U8.3 (D0), U10.3 (D0), U13.11 (I0b), U13.12 (O3a)
/D_{PET}1: J6.9, U6.32 (D1), U8.18 (D7), U10.18 (D7), U13.13 (I1b), U13.14 (O2a)
/D_{PET}2: J6.10, U6.31 (D2), U8.4 (D1), U10.4 (D1), U13.15 (I2b), U13.16 (O1a)
/D_{PET}3: J6.11, U6.30 (D3), U8.17 (D6), U10.17 (D6), U13.17 (I3b), U13.18 (O0a)
/D_{PET}4: J6.12, U6.29 (D4), U8.7 (D2), U10.7 (D2), U18.11 (I0b), U18.12 (O3a)
/D_{PET}5: J6.13, U6.28 (D5), U8.14 (D5), U10.14 (D5), U18.13 (I1b), U18.14 (O2a)
/D_{PET}6: J6.14, U6.27 (D6), U8.8 (D3), U10.8 (D3), U18.15 (I2b), U18.16 (O1a)
/D_{PET}7: J6.15, U6.26 (D7), U8.13 (D4), U10.13 (D4), U18.17 (I3b), U18.18 (O0a)
/D_{RAM}0: J3.3, U11.4, U18.6 (I2a), U18.7 (O1b)
/D_{RAM}1: J3.2, U11.13, U18.4 (I1a), U18.5 (O2b)
/D_{RAM}2: J3.1, U11.1, U18.2 (I0a), U18.3 (O3b)
/D_{RAM}3: J3.8, U12.10, U13.8 (I3a), U13.9 (O0b)
/D_{RAM}4: J3.7, U12.4, U13.6 (I2a), U13.7 (O1b)
/D_{RAM}5: J3.6, U12.13, U13.4 (I1a), U13.5 (O2b)
/D_{RAM}6: J3.5, U12.1, U13.2 (I0a), U13.3 (O3b)
/D_{RAM}7: J3.4, U11.10, U18.8 (I3a), U18.9 (O0b)
/E: J6.18, U6.23 (E)
/GRAPHIC: J4.19 (A10), U7.19 (A10)
/INIT: U7.21 (CS3), U9.1 (OEa), U9.19 (OEb), U17.6 (~Q)
/INVERT: J5.16, U6.16 (MA12)
/LPSTB: J5.3, U6.3 (LPSTB)
/M_{A}0: J1.9, J5.4, U6.4 (MA0)
/M_{A}1: J1.11, J5.5, U6.5 (MA1)
/M_{A}2: J1.13, J5.6, U6.6 (MA2)
/M_{A}3: J1.15, J5.7, U6.7 (MA3)
/M_{A}4: J1.17, J5.8, U6.8 (MA4)
/M_{A}5: J1.19, J5.9, U6.9 (MA5)
/M_{A}6: J1.21, J5.10, U6.10 (MA6)
/M_{A}7: J1.23, J5.11, U6.11 (MA7)
/M_{A}8: J1.25, J5.12, U6.12 (MA8)
/M_{A}9: J1.27, J5.13, U6.13 (MA9)
/M_{A}10: J5.14, U6.14 (MA10)
/M_{A}11: J5.15, U6.15 (MA11)
/NOROW1: J6.6, U6.35 (RA3)
/NOROW2: J6.7, U6.34 (RA4)
/OEa: U5.6, U13.1 (~OEa), U15.4, U18.1 (~OEa)
/OEb: U5.8, U13.19 (~OEb), U14.1 (A), U15.1, U15.2, U15.5, U18.19 (~OEb)
/RRA0: J4.8 (A0), U7.8 (A0)
/RRA1: J4.7 (A1), U7.7 (A1)
/RRA2: J4.6 (A2), U7.6 (A2)
/RS: J6.17, U6.24 (RS)
/R_{A}0: J1.1, J6.3, U6.38 (RA0)
/R_{A}1: J1.3, J6.4, U6.37 (RA1)
/R_{A}2: J1.5, J6.5, U6.36 (RA2)
/Switch_{A}: J2.2, U2.11, U14.2 (B), U15.6
/VSYNC: J6.1, U6.40 (VSYNC)
/~CLK_latch: U16.3 (C), U16.8 (~Q)
/~CS_{PET}1: J4.20 (~CS1), U7.20 (~CS1)
/~CS: U4.5 (4), U6.25 (~CS)
/~CS_{PET}: J6.16, U4.12 (A3)
/~OE: J2.1, U15.3
/~RESET: J5.2, U6.2 (~RESET), U10.1 (~Mr)
/~WE: J2.3, U15.8
BA1: H2.1, U3.1, U4.15 (A0)
BA3: H3.1, U3.2, U4.14 (A1)
CLK: J6.20, U6.21 (CLK), U16.12 (D)
CLK_latch: J1.7, U16.9 (Q)
D_{CHAR}0: J4.9 (D0), U7.9 (D0), U9.9 (O0b)
D_{CHAR}1: J4.10 (D1), U7.10 (D1), U9.12 (O3a)
D_{CHAR}2: J4.11 (D2), U7.11 (D2), U9.7 (O1b)
D_{CHAR}3: J4.13 (D3), U7.13 (D3), U9.14 (O2a)
D_{CHAR}4: J4.14 (D4), U7.14 (D4), U9.5 (O2b)
D_{CHAR}5: J4.15 (D5), U7.15 (D5), U9.16 (O1a)
D_{CHAR}6: J4.16 (D6), U7.16 (D6), U9.3 (O3b)
D_{CHAR}7: J4.17 (D7), U7.17 (D7), U9.18 (O0a)
GND: C1.2, C2.2, C3.2, C5.2, C7.2, C8.2, J2.6, J2.7, J4.12 (VSS), J5.1, U1.7 (GND), U2.7 (GND), U3.7 (GND), U4.8 (GND), U5.7 (GND), U6.1 (VSS), U7.12 (VSS), U8.1 (OE), U8.10 (GND), U9.10 (GND), U10.10 (GND), U11.7 (GND), U12.7 (GND), U13.10 (GND), U14.8 (GND), U14.9 (A), U15.7 (GND), U16.7 (GND), U17.7 (GND), U18.10 (GND)
HSYNC: J6.2, U6.39 (HSYNC), U14.10 (B)
LSD0: J4.5 (A3), U2.13, U7.5 (A3)
LSD1: J4.4 (A4), U2.1, U7.4 (A4)
LSD2: J4.3 (A5), U1.9, U7.3 (A5)
LSD3: J4.2 (A6), U1.5, U7.2 (A6)
LSD4: J4.1 (A7), U1.11, U7.1 (A7)
LSD5: J4.23 (A8), U1.1, U7.23 (A8)
LSD6: J4.22 (A9), U1.13, U7.22 (A9)
unnamed: C5.1, U15.9, U15.10, U15.11
unnamed: R1.2, U1.2, U1.3
unnamed: R3.2, U2.4, U2.5
unnamed: U3.6, U5.5
unnamed: U3.10, U3.11
unnamed: U3.3, U3.12, U3.13
unnamed: U3.4, U3.5, U4.4 (3), U5.2
unnamed: U2.9, U4.6 (5)
unnamed: U2.3, U4.9 (7), U5.1
unnamed: U3.8, U4.13 (A2)
unnamed: U5.3, U5.9
unnamed: U5.10, U5.11
unnamed: R4.2, U2.8, U8.11 (LE)
unnamed: U9.2 (I0a), U11.3
unnamed: U9.11 (I0b), U12.8
unnamed: U9.4 (I1a), U11.6
unnamed: U9.13 (I1b), U12.11
unnamed: U9.6 (I2a), U12.3
unnamed: U9.15 (I2b), U11.8
unnamed: U9.8 (I3a), U12.6
unnamed: U9.17 (I3b), U11.11
unnamed: U10.11 (Cp), U17.8 (~Q)
unnamed: U10.9 (Q3), U11.2, U11.5, U11.9, U11.12, U12.2, U12.5, U12.9, U12.12
unnamed: U10.12 (Q4), U17.1 (~R)
unnamed: C6.1, U14.14 (Cext)
unnamed: C6.2, R6.2, U14.15 (RCext)
unnamed: U14.4 (~Q), U15.12, U15.13
unnamed: C4.1, U14.6 (Cext)
unnamed: U14.5 (Q), U16.2 (D)
unnamed: C4.2, R5.2, U14.7 (RCext)
unnamed: U14.12 (~Q), U16.4 (~S)
unnamed: U3.9, U16.5 (Q)
unnamed: R2.2, U1.4, U1.6, U1.8, U1.10, U1.12, U2.2, U2.10, U2.12, U17.2 (D)
unnamed: U4.7 (6), U17.12 (D)
RDY: H4.1, U2.6
R/~W: J6.19, U5.4, U5.12, U5.13, U6.22 (R/~W), U17.11 (C)

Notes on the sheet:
THE DATA PECKER
CRTC SOCKET
CHARROM SOCKET
READ/WRITE LOCAL RAM
CHARROM ADAPTER
SWITCH CHARACTERS AND GFX
CHARROM
INVERT GFX DATA

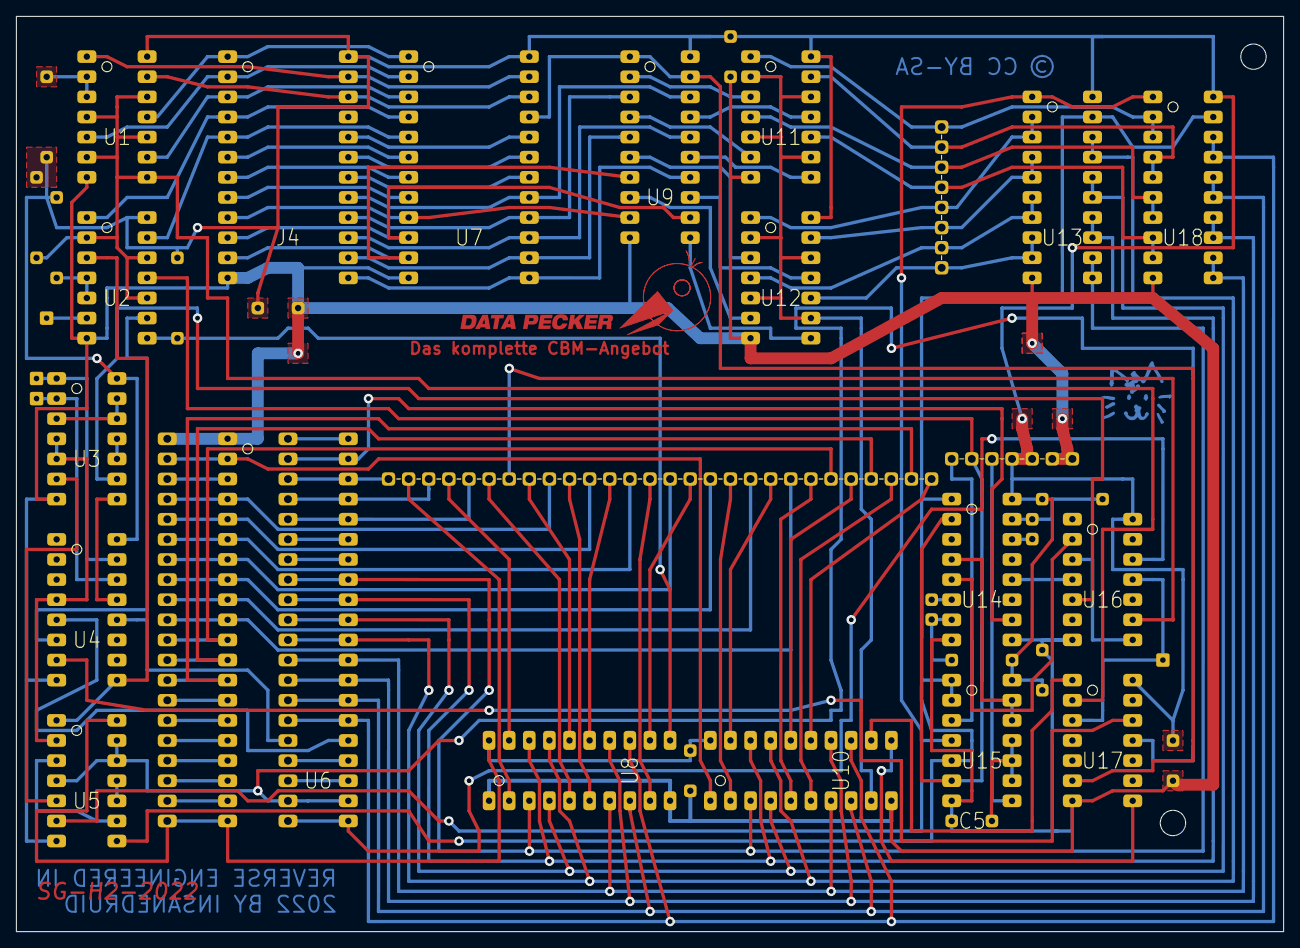
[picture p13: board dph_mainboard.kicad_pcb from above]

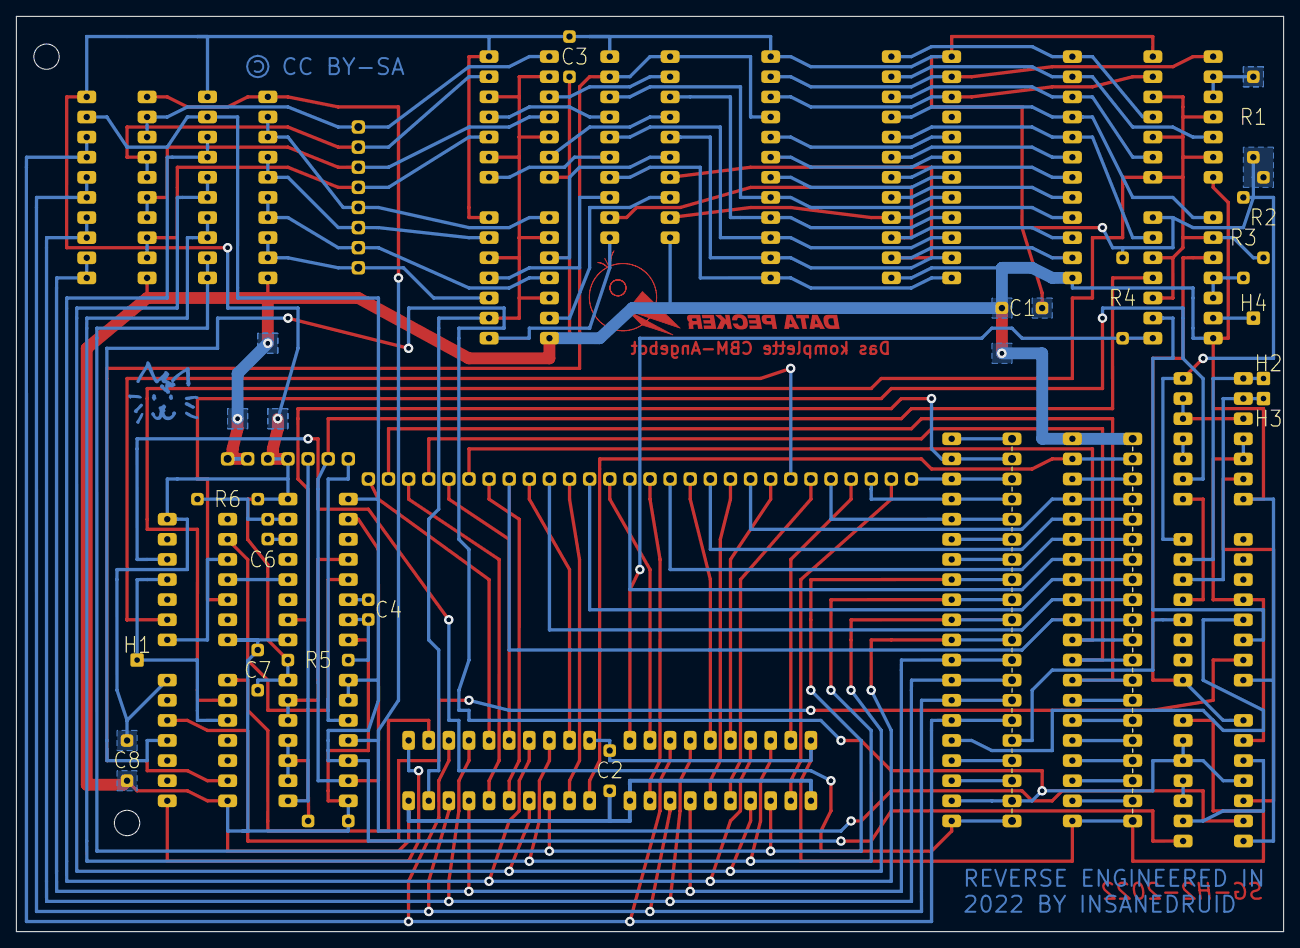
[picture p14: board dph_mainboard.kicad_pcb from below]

Board: 2 copper layers, 160.0 x 115.6 mm, 42 parts (2 on the bottom side), 131 nets.

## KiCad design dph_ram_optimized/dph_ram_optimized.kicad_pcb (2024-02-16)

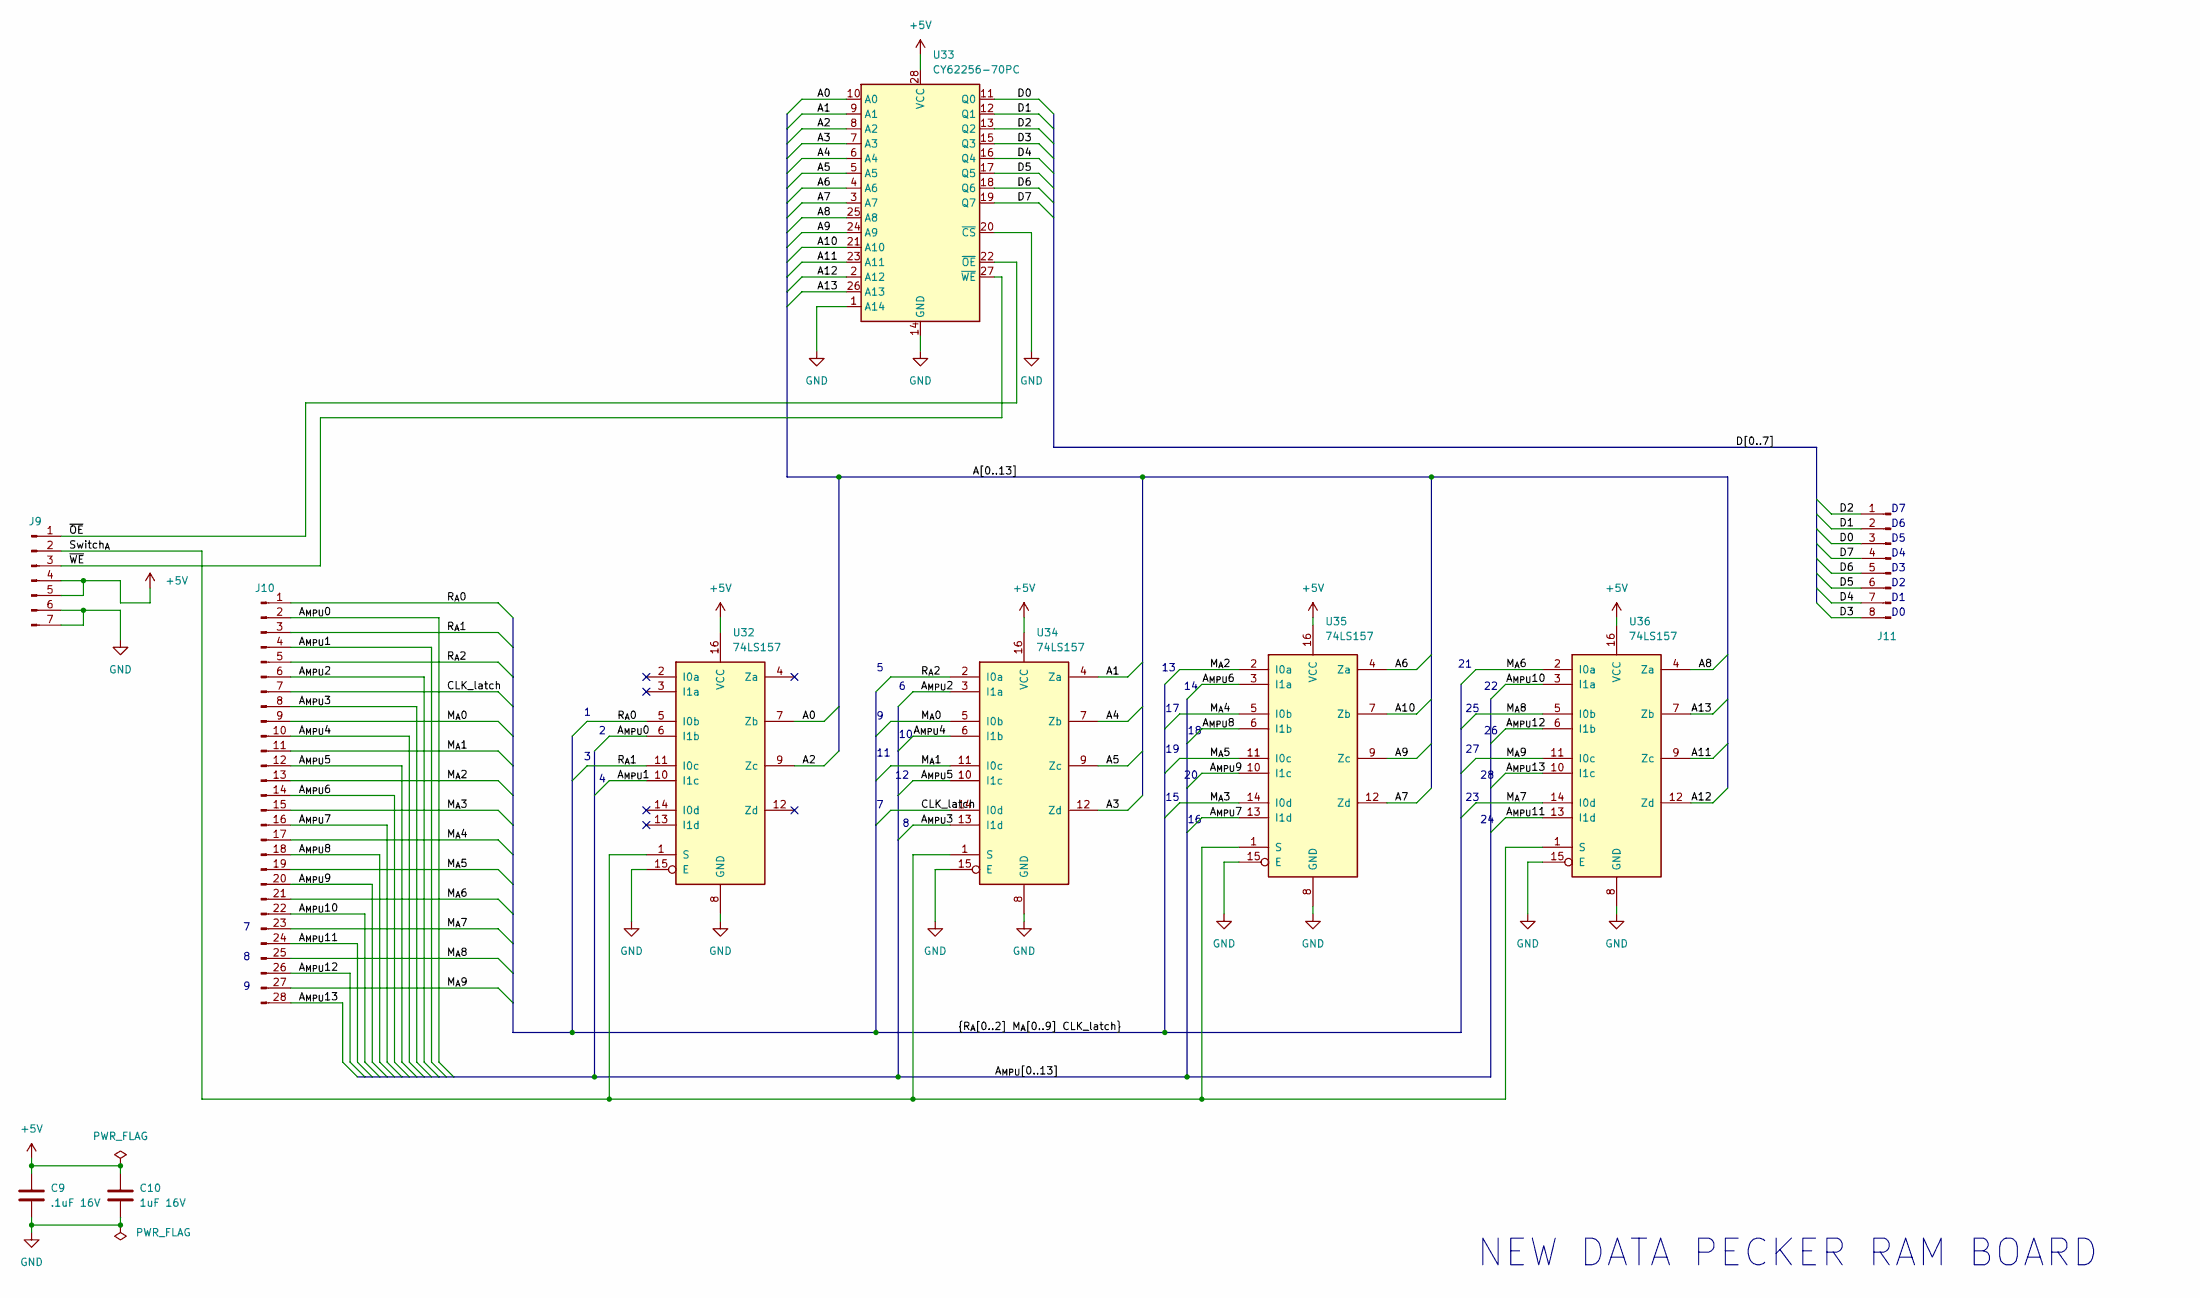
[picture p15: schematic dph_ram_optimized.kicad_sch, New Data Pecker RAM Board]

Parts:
C9: .1uF 16V; C_Disc_D4.3mm_W1.9mm_P5.08mm
C10: 1uF 16V; C_Disc_D3.0mm_W1.6mm_P2.50mm
J9: Conn_01x07_Pin; PinHeader_1x07_P2.54mm_Vertical
J10: Conn_01x28_Pin; PinHeader_1x28_P2.54mm_Vertical
J11: Conn_01x08_Pin; PinHeader_1x08_P2.54mm_Vertical
U32, U34, U35, U36: 74LS157; DIP-16_W7.62mm_LongPads
U33: CY62256-70PC; DIP-28_W15.24mm_LongPads

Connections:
+5V: C9.1, C10.1, J9.4, J9.5, U32.16 (VCC), U33.28 (VCC), U34.16 (VCC), U35.16 (VCC), U36.16 (VCC)
/A0: U32.7 (Zb), U33.10 (A0)
/A1: U33.9 (A1), U34.4 (Za)
/A2: U32.9 (Zc), U33.8 (A2)
/A3: U33.7 (A3), U34.12 (Zd)
/A4: U33.6 (A4), U34.7 (Zb)
/A5: U33.5 (A5), U34.9 (Zc)
/A6: U33.4 (A6), U35.4 (Za)
/A7: U33.3 (A7), U35.12 (Zd)
/A8: U33.25 (A8), U36.4 (Za)
/A9: U33.24 (A9), U35.9 (Zc)
/A10: U33.21 (A10), U35.7 (Zb)
/A11: U33.23 (A11), U36.9 (Zc)
/A12: U33.2 (A12), U36.12 (Zd)
/A13: U33.26 (A13), U36.7 (Zb)
/A_{MPU}0: J10.2, U32.6 (I1b)
/A_{MPU}1: J10.4, U32.10 (I1c)
/A_{MPU}2: J10.6, U34.3 (I1a)
/A_{MPU}3: J10.8, U34.13 (I1d)
/A_{MPU}4: J10.10, U34.6 (I1b)
/A_{MPU}5: J10.12, U34.10 (I1c)
/A_{MPU}6: J10.14, U35.3 (I1a)
/A_{MPU}7: J10.16, U35.13 (I1d)
/A_{MPU}8: J10.18, U35.6 (I1b)
/A_{MPU}9: J10.20, U35.10 (I1c)
/A_{MPU}10: J10.22, U36.3 (I1a)
/A_{MPU}11: J10.24, U36.13 (I1d)
/A_{MPU}12: J10.26, U36.6 (I1b)
/A_{MPU}13: J10.28, U36.10 (I1c)
/CLK_latch: J10.7, U34.14 (I0d)
/D0: J11.3, U33.11 (Q0)
/D1: J11.2, U33.12 (Q1)
/D2: J11.1, U33.13 (Q2)
/D3: J11.8, U33.15 (Q3)
/D4: J11.7, U33.16 (Q4)
/D5: J11.6, U33.17 (Q5)
/D6: J11.5, U33.18 (Q6)
/D7: J11.4, U33.19 (Q7)
/M_{A}0: J10.9, U34.5 (I0b)
/M_{A}1: J10.11, U34.11 (I0c)
/M_{A}2: J10.13, U35.2 (I0a)
/M_{A}3: J10.15, U35.14 (I0d)
/M_{A}4: J10.17, U35.5 (I0b)
/M_{A}5: J10.19, U35.11 (I0c)
/M_{A}6: J10.21, U36.2 (I0a)
/M_{A}7: J10.23, U36.14 (I0d)
/M_{A}8: J10.25, U36.5 (I0b)
/M_{A}9: J10.27, U36.11 (I0c)
/R_{A}0: J10.1, U32.5 (I0b)
/R_{A}1: J10.3, U32.11 (I0c)
/R_{A}2: J10.5, U34.2 (I0a)
/Switch_{A}: J9.2, U32.1 (S), U34.1 (S), U35.1 (S), U36.1 (S)
/~OE: J9.1, U33.22 (~OE)
/~WE: J9.3, U33.27 (~WE)
GND: C9.2, C10.2, J9.6, J9.7, U32.8 (GND), U32.15 (E), U33.1 (A14), U33.14 (GND), U33.20 (~CS), U34.8 (GND), U34.15 (E), U35.8 (GND), U35.15 (E), U36.8 (GND), U36.15 (E)

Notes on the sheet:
NEW DATA PECKER RAM BOARD

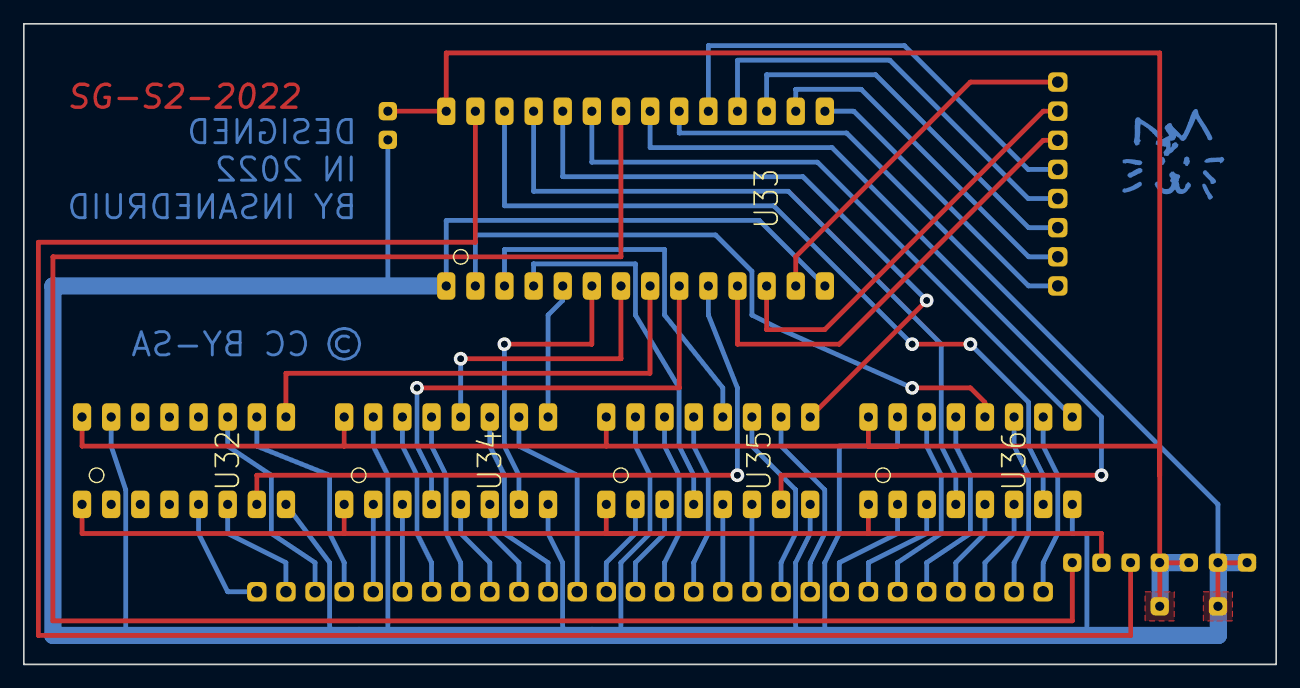
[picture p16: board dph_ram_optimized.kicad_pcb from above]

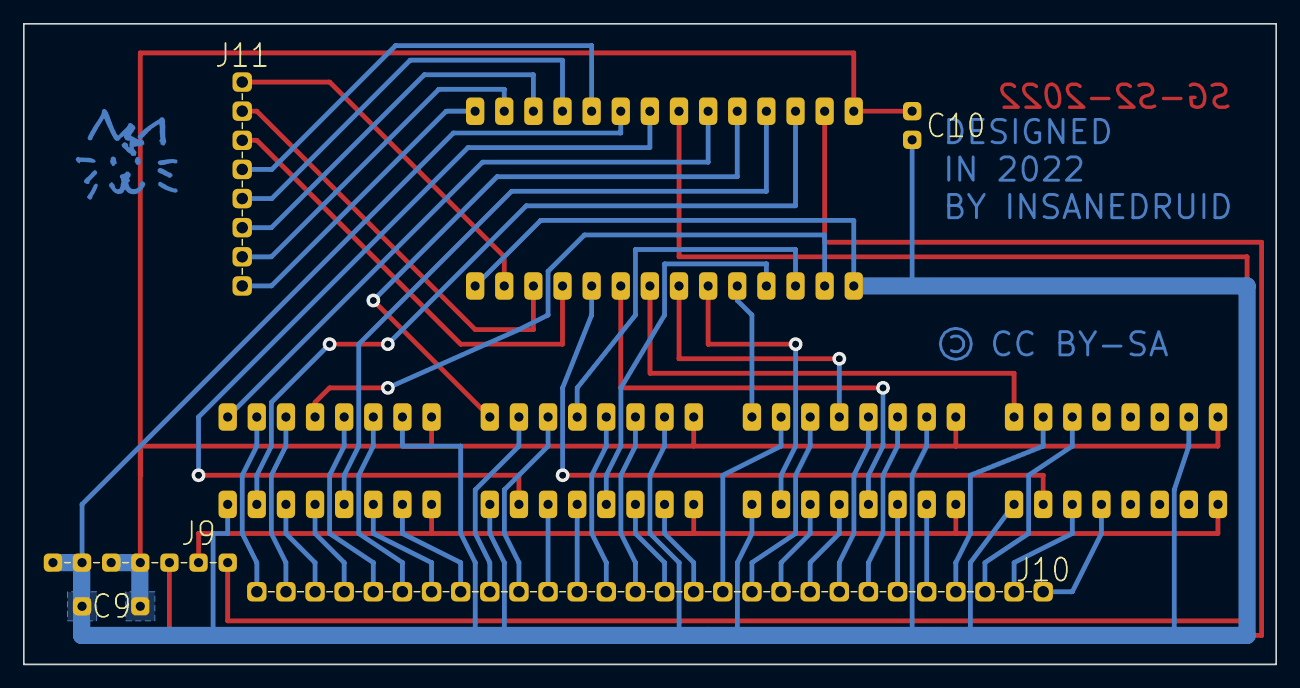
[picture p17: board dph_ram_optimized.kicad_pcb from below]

Board: 2 copper layers, 109.2 x 55.9 mm, 10 parts (3 on the bottom side), 55 nets.

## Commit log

2024-02-16 kicad drawing sheet fixes
    fixed license links in drawing sheets to match board prints, readme and project
    [dph_mainboard.kicad_pcb, dph_mainboard.kicad_sch, dph_ram.kicad_pcb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]
2024-02-26 fixed description for external wiring
    fixed and added UD3 Pin information for 8032030 and 8032090 boards

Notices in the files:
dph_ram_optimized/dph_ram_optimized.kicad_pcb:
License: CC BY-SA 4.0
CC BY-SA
